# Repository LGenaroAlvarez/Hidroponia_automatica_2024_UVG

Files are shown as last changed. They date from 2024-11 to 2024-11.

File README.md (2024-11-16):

<picture>
 <source media="(prefers-color-scheme: dark)" srcset="https://github.com/LGenaroAlvarez/Hidroponia_automatica_2024_UVG/blob/f2462ae6608f58484dead54a124a67f43fbc2c54/Logo%20UVG-08.png" width="150" height="33">
 <source media="(prefers-color-scheme: light)" srcset="https://github.com/LGenaroAlvarez/Hidroponia_automatica_2024_UVG/blob/f2462ae6608f58484dead54a124a67f43fbc2c54/Logo%20UVG-06.png" width="150" height="33">
 LOGO-UVG
</picture>

# Diseño e implementación de un sistema hidropónico automático de técnica NFT para el cultivo de cilantro en un entorno urbano

## Autor
**Nombre:** Luis Genaro Álvarez Sulecio

**Carné:** 20168

**Carrera:** Licenciatura en Ingeniería Mecatrónica

### Información de contacto
**Correo institucional:** alv21068@uvg.edu.gt

**Correo personal:** luis.genaro.alvarez@gmail.com

**LinkedIn:** [L. Genaro A. Sulecio](https://www.linkedin.com/in/l-genaro-a-sulecio-4034471aa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)

## Asesor
**Nombre:** Ing. Pedro Joaquín Castillo Coronado
### Información de contacto
**Correo institucional:** pjcastillo@uvg.edu.gt

## Contenido
| Ubicación | Descripción de archivos|
|---|---|
| Codigo Fuente | Código desarrollado para el moniotoreo y control del sistema (firmware) y código de la aplicación desarrollada en Android Studio |
| Datos | Recopilación de históricos de datos obtenidos durante los períodos de prueba del sistema hidropónico tanto en formato .csv como en formato .xlsx |
| Documentos | Protocolo y trabajo escrito del proyecto de graduación desarrollado en TeXstudio |
| Modelos CAD | Modelos 3D de las piezas diseñadas e utilizadas en el sistema, ensamblaje del sistema completo para visualizaión 3D y planos detallados para cada pieza diseñada |
| Desarrollo PCB | Diagramas de circuitos, archivos de ruteo e imágenes de la placa desarrollada | 
| OldVersions | Versiones previas de código desarrollado |

## Descripción
 Este repositorio cuenta con la documentación del sistema hidropónico automático utilizando técnica de solución nutritiva recirculante (NFT por sus siglas en inglés) desarrollado como trabajo de graduación. El proyecto establece las bases para crear un sistema funcional que permita el monitoreo de diferentes parámetros ambientales que influyen en el crecimiento de las plantas en un entorno hidroónico. El sistema utiliza la placa de desarrollo [ESP-WROOM-32 de HiLetgo](http://www.hiletgo.com/ProductDetail/1906566.html) para recolectar datos de temperatura y humedad ambiental, así como de temperatura y pH de la solución de crecimiento. Para esto se utilizaron una serie de sensores analógicos y digitales los cuales se integraron utilizando diferentes librerías de licencia abierta.

 Este proyecto es el primero en la línea de investigación de **Agricultura de Precisión**.

## Desglose del sistema

### Firmware y software

* Sistema físico con lectura de sensores y control de actuadores, programado en la IDE de Arduino.
* Aplicación móvil para la visualización de la información recopilada por el sistema, programado en JAVA y XML.
* Sistema de registro de datos para generación de históricos, programado en Python.

### Controlador y sensores

* Sensores de temperatura y humedad ambiental [DHT11](https://www.adafruit.com/product/386)
* Sensores de temperatura del agua [DS18B20](https://www.adafruit.com/product/381)
* Sensor de pH en el agua [ENV-30-pH](https://atlas-scientific.com/kits/surveyor-analog-ph-kit/)
* Reloj de tiempo real RTC [DS3231](https://laelectronica.com.gt/modulo-de-reloj-rtc-ds3231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)
* Relés de 5VDC para control de elementos de 120VAC [Shori S3H-5-1CS](https://tienda.tettsa.gt/producto/relay-5vdc-5-pines-spdt-shori/)
* Placa de desarrollo [ESP WROOM-32](https://laelectronica.com.gt/modulo-wi-fi--bluetooth-esp32?search=esp32&description=true)

### Diseño de estructura física

La estructura física se basó al rededor de una estantería metálica modular. Esta cuenta con 5 repisas, de las cuales se utilizaron dos para los canales de crecimiento. En el ensamblaje del modelo CAD se observa la disposición de las tuberías para los canales de crecimiento, así como la posición de los sensores de temperatura y humedad ambiental.

<picture>
 ESTRUCTURA-SISTEMA-HIDROPONICO
</picture>

### Lenguajes de programación

* Python 3.11.9
* Arduino C
* Java
* XML

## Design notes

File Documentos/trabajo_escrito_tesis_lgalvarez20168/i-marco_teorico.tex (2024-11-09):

\section{Cultivos hidropónicos}
Históricamente, la agricultura tradicional ha utilizado el suelo como medio principal para el crecimiento de plantas gracias a su alta concentración de minerales y nutrientes esenciales para el desarrollo de hojas y frutos. Debido al crecimiento poblacional observado en los últimos siglos, las metodologías de agricultura tradicional han extraído una cantidad considerable de nutrientes del suelo, reduciendo su productividad y aumentando su dependencia de fertilizantes añadidos. 

A mediados del siglo pasado, se empezaron a investigar una técnicas de agricultura con tal de eliminar la dependencia del suelo para el crecimiento de las plantas. Una de las soluciones encontradas fueron los cultivos hidropónicos los cuales no dependen de un sustrato para entregar minerales y nutrientes esenciales para el crecimiento de las plantas, sino se aprovechan de una solución de estos en agua para maximizar la absorción por medio de las raíces \cite{raviv_soilless_2019}. Los sistemas hidropónicos se caracterizan por su bajo consumo de agua, alta eficiencia de espacio y altos niveles de productividad. Se destaca que estos sistemas no dependen de las condiciones climáticas de la región, al encontrarse en un entorno controlado, como un invernadero. Esto permite una producción constante a lo largo del año la cual no es susceptible a sequías o inundaciones. Adicionalmente, al no depender del suelo, estos sistemas se pueden expandir de manera vertical, lo cual aumenta la producción de plantas por metro cuadrado utilizado. Estas características han vuelto a la hidroponía una de las soluciones más prometedoras en el contexto del crecimiento urbano y poblacional visto en el siglo XXI. Otra de las grandes ventajas de contar con un entorno cerrado y controlable, es que los cultivos hidropónicos raras veces se encuentran expuestos a pestes o enfermedades relacionadas al suelo. Sin embargo, su dependencia de un control constante y riguroso de parámetros, hace de esta metodología de cultivo susceptible a pérdidas por mal manejo del sistema \cite{raviv_soilless_2019}.

\section{Solución nutritiva re-circulante (NFT)}
La hidroponía cuenta con una gran variedad de métodos ideados con la finalidad de maximizar espacio, eficiencia de distribución de materiales y otros parámetros de crecimiento de las plantas \cite{rajaseger_hydroponics_2023}. La principal diferencia entre los métodos de cultivo hidropónico consiste en los métodos de irrigación. El método de solución nutritiva re-circulante (\textit{Nutrient Film Technique}), también conocido como método NFT, utiliza un sistema de irrigación que genera una película delgada de agua con nutrientes que fluye sobre las raíces de las plantas. Tradicionalmente, estos sistemas se implementan con una serie de canaletas o tuberías colocadas a una inclinación de entre 0.3\% y 2\% \cite{van_os_technical_2019}. Una de las características más retadoras del método NFT consiste en el control de parámetros, como lo son los niveles de pH de la solución, su temperatura, oxígeno disuelto y saturación de nutrientes \cite{baiyin_flow_rate_2021}. Adicionalmente, varios estudios han demostrado que la tasa de flujo de la solución en el sistema se encuentra fuertemente relacionada con el rendimiento del crecimiento de las plantas. En el caso de las lechugas, Al-Tawaha y colaboradores encontraron que un flujo de 20 L/minuto fue óptimo para el desarrollo de las plantas, llevando a un mayor rendimiento \cite{al-tawaha_flow_rate_nft_2018}. Finalmente, es importante destacar que este sistema requiere que las plantas sean germinadas en un espacio separado, antes de que puedan ser introducidas al sistema.

\begin{figure}[H]
	\centering
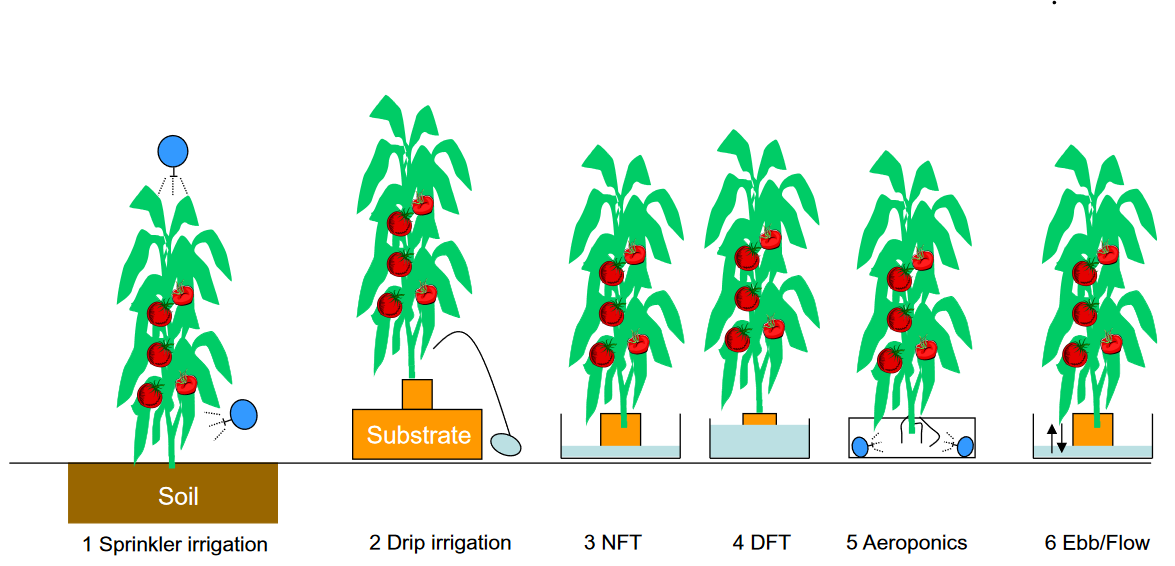
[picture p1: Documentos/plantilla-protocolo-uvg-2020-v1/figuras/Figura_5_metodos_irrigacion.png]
	
	\caption{Variedad de métodos de irrigación para cultivos \cite{van_os_technical_2019}.}
	\label{fig:mesh5}
\end{figure}

\begin{figure}[H]
	\centering
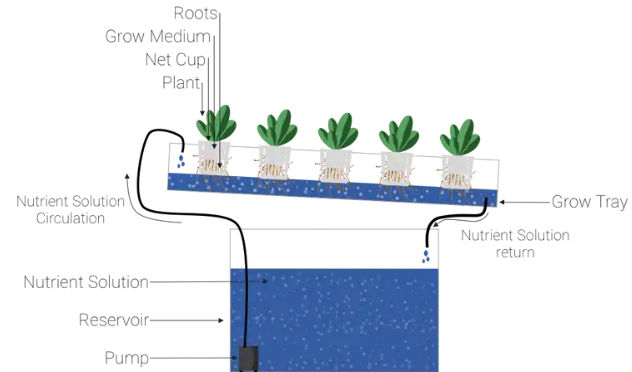
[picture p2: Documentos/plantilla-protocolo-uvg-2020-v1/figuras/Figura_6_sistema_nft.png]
	
	\caption{Diagrama simplificado de metodología NFT para cultivos hidropónicos \cite{NutrientFilmTechnique_2023}.}
	\label{fig:mesh6}
\end{figure}

\section{Solución de nutrientes}
Acceso constante a luz solar, agua, oxígeno y dióxido de carbono es esencial para la supervivencia de las plantas. Sin embargo, esto no es lo único que requieren para su crecimiento. Normalmente, las plantas obtienen la mayoría de los minerales y nutrientes necesarios para su crecimiento del suelo, el cual, a lo largo de varios años por procesos naturales, ha acumulado en diferentes cantidades. Las plantas requieren de 13 nutrientes minerales necesarios para su desarrollo y crecimiento adecuado. Sus características de crecimiento y la calidad de las plantas estarán definidas por el porcentaje de nutrientes que tengan disponibles y que sean capaces de absorber \cite{marulanda_huerta_2003}. Estos nutrientes se pueden dividir en tres categorías según la función que cumple cada elemento. La primera categoría se conoce como los macro-nutrientes, estos son nutrientes que las plantas requieren en altas cantidades pues son esenciales para el desarrollo de las estructuras fundamentales para su crecimiento. En este grupo se encuentran el Nitrato requerido para el desarrollo de hojas y tallos; el Fósforo, requerido para el desarrollo de raíces, la formación de semillas y la maduración de frutos; y el Potasio, requerido para el desarrollo de frutos y la acumulación de nutrientes en la planta \cite{marulanda_huerta_2003}.

La segunda categoría consiste en minerales requeridos para el correcto desarrollo de la planta, sin embargo, estos son requeridos en cantidades más bajas por lo que se conocen como elementos secundarios. Entre estos se encuentra el Calcio, el cual activa la formación de raíces, especialmente en las primeras etapas de desarrollo y neutraliza las sustancias tóxicas producidas por la planta. También se encuentra el Azufre, el cual es esencial en la producción de proteínas, mejora el crecimiento de la planta y facilita el desarrollo de semillas. Adicionalmente, en este grupo se cuenta con el Magnesio, el cual es fundamental para las plantas porque es requerido para la creación de clorofila y las azúcares que requieren para vivir, adicionalmente es utilizado para regular los nutrientes dentro de la planta y fomenta la creación de aceites y grasas \cite{marulanda_huerta_2003}. Finalmente, se cuenta con una serie de micro-nutrientes, los cuales cumplen una gran variedad de funciones que facilitan el desarrollo de la planta y aseguran un mayor rendimiento de la misma. Estos se detallan a continuación \cite{atlas_scientific_nutrient_2023}:

\begin{itemize}
	\item Cloro\\
	Utilizado para facilitar el proceso de fotosíntesis y regular los niveles de sales y líquido en las células lo cual asegura una planta fresca y saludable.
	\item Molibdeno\\
	Elemento esencial para la fijación de nitrógeno y utilizado en el proceso de conversión de nitrato a amoniaco.
	\item Manganeso\\
	De gran utilidad para aumentar la resiliencia de las plantas ante situaciones de alto estrés, y utilizado en el proceso de activación de enzimas.
	\item Zinc\\
	Requerido para la síntesis de hormonas de crecimiento y el desarrollo de raíces.
	\item Boro\\
	Apoya en el proceso de crecimiento al fomentar la división de células y el metabolismo de carbohidrátos.
	\item Hierro\\
	Esencial para la transferencia de energía entre células y la producción de clorofila.
	\item Cobre\\
	Mejora la estructura de las plantas al reforzar las paredes celulares mediante la formación de lignina. Esencial en la creación de estructuras maderosas.
\end{itemize}

El correcto suministro y balance de estos componentes en un sistema hidropónico es esencial para asegurar el crecimiento adecuado y el rendimiento de los cultivos. Ahora bien, su aplicación y control de manera individual sería sumamente difícil, por esta razón, se han desarrollado fórmulas para proveer estos nutrientes en un sistema hidropónico. En la industria estas soluciones se conocen como solución concentrada A y B, donde la primera cuenta con los macro-nutrientes y nutrientes secundarios, mientras que la segunda cuenta con los micro-nutrientes \cite{marulanda_huerta_2003}. Estas soluciones pueden ser creadas de manera independiente, o se pueden adquirir en el mercado. Es importante destacar que los porcentajes de concentración a utilizar en el sistema hidropónico dependerá del tipo de cultivo y sus requisitos. Por ejemplo, un cultivo de hortalizas requerirá mayores porcentajes de nitrógeno y nutrientes secundarios, mientras que plantas con flores y frutos, requerirán una mayor concentración de fósforo y potasio. Así mismo, cambios en la temperatura requerirán de un ajuste en la concentración total en el agua, puesto que, a mayores temperaturas, las plantas aumentarán su consumo de agua, mas no su dependencia en minerales, mientras que a menores temperaturas, se ve lo opuesto \cite{marulanda_huerta_2003}.

\section{Características de la solución nutritiva del cilantro}
El cilantro es una hierba bastante versátil la cual requiere de una baja cantidad de nutrientes con tal de presentar una productividad significativa. De los nutrientes mencionados anteriormente, el cilantro requiere únicamente un control rigoroso de los macro-nutrientes principales así como una baja cantidad de Calcio y Magnesio \cite{letpot_nodate}. Este control de macro-nutrientes va de la mano con una regulación cuidadosa de la temperatura del agua. Esto pues, en diferentes rangos de temperatura varía la necesidad de nutrientes así como su facilidad de absorción \cite{voogt_nutrient_2019}.

Según el estudio realizado por Currey y colaboradores, uno de los factores que más interfiere en el crecimiento y desarrollo del cilantro es la cantidad de fotones que reciben las plantas durante el día. Esto se puede traducir a la cantidad de horas de luz que requieren para su crecimiento óptimo, el cual se encuentra en un rango de 12 a 16 horas de luz diarias \cite{letpot_nodate}. Una conclusión importante del estudio de Currey y colaboradores es que si bien la concentración de luz disponible para la planta aumenta su productividad, no es necesario realizar un ajuste de la densidad de nutrientes debido al aumento en concentración de luz \cite{currey_nutrient_2019}. A continuación se detallan los parámetros del agua requeridos para el correcto desarrollo del cilantro en un sistema hidropónico:

\begin{table}[H]
	\centering
	\begin{tabular}{|c|c|}
		\hline
		\multicolumn{2}{|c|}{\textbf{Características de la solución nutritiva}}\\ \hline
		Concentración de nutrientes: & 1.2 a 1.8 mS/cm \\ \hline
		Potencia de hidrógeno (pH): & 5.5 a 6.7 \\ \hline
		Temperatura del agua: & 15 a 20 °C \\ \hline
		Nutrientes requeridos: & Nitrógeno, fósforo, potasio, calcio y magnesio \\ \hline
		Concentración de nutrientes: & NPK 15:15:15\\ \hline
		Nutrientes adicionales: &  0.5\% Nitrato de calcio y 0.5\% Sulfato de magnesio\\ \hline
		Tiempo de crecimiento: & 50 a 55 días\\ \hline
		Espacio entre plantas: & 18 cm \\ \hline
	\end{tabular}
	\caption{Parámetros esenciales para el crecimiento de Cilantro en sistemas hidropónicos \cite{mondol_use_2023} \cite{letpot_nodate}.}
	\label{Cuadro0}
\end{table}

\section{Monitoreo de parámetros para el crecimiento de plantas}
Como se detalló anteriormente, los cultivos hidropónicos requieren de un control constante y preciso de una gran variedad de parámetros. El monitoreo adecuado de parámetros como el nivel de oxigenación del agua, la cantidad de nutrientes, el nivel de acidez de la solución, la temperatura del ambiente, temperatura del agua, y el nivel de humedad son esenciales para asegurar el crecimiento óptimo de las plantas. Tradicionalmente, estos parámetros se miden con una serie de pruebas químicas o sensores independientes. A continuación, se detallan los diferentes sensores que se pueden utilizar en un cultivo hidropónico para medir los parámetros del agua así como la importancia de cada uno de dichos parámetros.

\subsection{Oxígeno disuelto en agua}
Los sistemas hidropónicos se enfrentan a varios retos, entre estos, la cantidad de oxígeno disuelto en la solución de nutrientes. Este parámetro es esencial para el desarrollo saludable de las raíces, puesto que con bajos niveles de oxígeno, estas pueden experimentar una enfermedad conocida como hipoxia. Según el estudio realizado por Roosta, los niveles de oxígeno están directamente relacionados no sólo con el crecimiento de las raíces, sino también con los procesos fotosintéticos y de crecimiento de los cultivos hidropónicos. Este parámetro afecta la absorción de Nitrógeno ya sea que se encuentre en la forma de sales de nitratos o amoníacos\cite{roosta_responses_2024}. La concentración de oxígeno disuelto se mide en mg/L, lo cual se puede lograr con una gran variedad de sensores.

\subsection{\textit{SEN0237 Gravity Analog Dissolved Oxygen Sensor} de \textit{DFRobot}}
El sensor analógico de oxígeno disuelto consiste en una sonda galvánica equipada con un electrodo el cual junto con una solución de hidróxido de sodio, también conocido como sosa cáustica, es capaz de detectar la concentración de oxígeno disuelto en agua. Dicho sensor debe ser calibrado antes de que se pueda utilizar, sin embargo, dicho proceso es relativamente sencillo \cite{DFRobot_DOsensor}. 

Según el fabricante, el sensor se puede calibrar utilizando un método de punto singular o de doble punto. El primer proceso requiere de la preparación de una solución de oxígeno concentrado en agua, esto se puede lograr utilizando un batidor o con una bomba de aire inmersa en el agua destilada durante 10 minutos. Una vez terminen los 10 minutos, se espera a que dejen de salir burbujas, y se sumerge la sonda en la solución. Se mantienen mezclando la solución lentamente para evitar burbujas hasta que el nivel de voltaje se estabilice y se guardan los valores de temperatura y voltaje como punto de saturación. El proceso de doble punto es similar al descrito anteriormente, sin embargo, requiere de dos soluciones a dos temperaturas diferentes. Se recomienda que una se encuentre alrededor de 5°C y la otra entre los 35° y 38°C \cite{DFRobot_DOsensor}. 

A continuación, se detallan las características del sensor:

\begin{table}[H]
	\centering
	\begin{tabular}{|c|c|}
		\hline
		\multicolumn{2}{|c|}{\textbf{Sonda del sensor de oxígeno disuelto}}\\ \hline
		Rango de detección: & 0 a 20 mg/L \\ \hline
		Rango de temperatura: & 0 a 40 °C \\ \hline
		Tiempo de respuesta: & 90 segundos a 25 °C \\ \hline
		Rango de presión: & 0 a 50 PSI \\ \hline
		Vida útil del electrodo: & 1 año (bajo condiciones normales de uso) \\ \hline
		Tiempo de reemplazo de membrana: & Cada 4 a 5 meses en agua clara \\ \hline
		Tiempo de reemplazo de solución: & Una vez al mes \\ \hline
		Largo del cable: & 2 metros \\ \hline
		Tipo de conector de la sonda: & BNC \\ \hline
		\multicolumn{2}{|c|}{\textbf{Placa de conversión de señales del sensor}}\\ \hline 
		Voltaje de alimentación: & 3.3 a 5.5 VDC \\ \hline
		Voltaje de señal de salida: & 0 a 3.3 VDC \\ \hline
		Cable de conexión: & BNC \\ \hline
		Conector de señal: & Interfaz PH2.0 - 3 pin \\ \hline
		Dimensiones: & 42mm $\times$ 32mm (1.65in $\times$ 1.26in) \\ \hline
	\end{tabular}
	\caption{Características de funcionamiento del sensor SEN0237 de \textit{DFRobot}.}
	\label{Cuadro1}
\end{table}

\begin{figure}[H]
	\centering
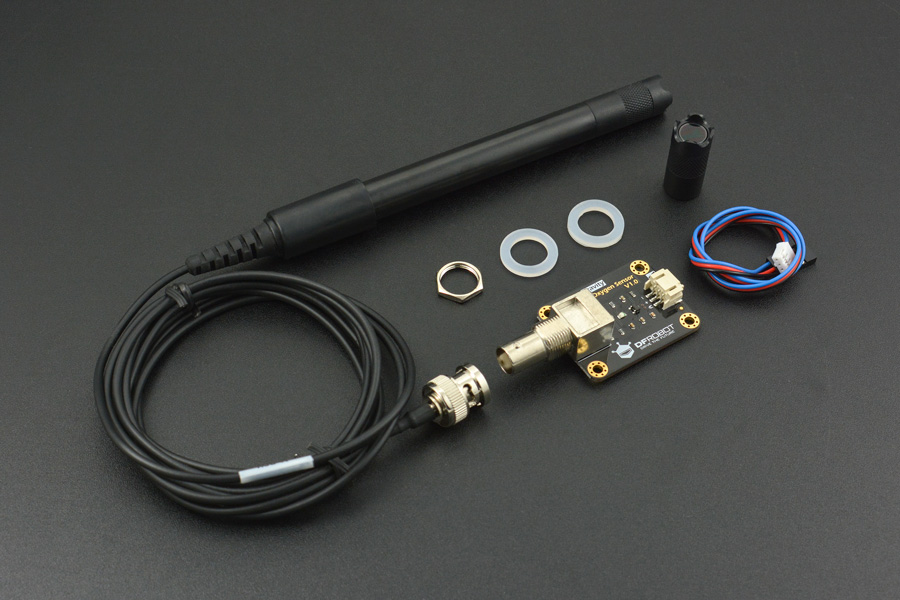
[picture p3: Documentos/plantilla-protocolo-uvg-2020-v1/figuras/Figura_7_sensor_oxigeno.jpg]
	
	\caption{Sensor analógico de oxígeno disuelto \cite{DFRobot_DOsensor}.}
	\label{fig:mesh7}
\end{figure}

\subsection{Sensor de electro conductividad (EC)}
Las soluciones de nutrientes requeridas para el crecimiento de las plantas cuentan con compuestos en la forma de sales, las cuales afectan la conductividad eléctrica del agua. Estas variaciones permiten utilizar los sensores de electro conductividad para determinar de manera aproximada la concentración de solución nutritiva en el agua de riego. La conductividad, medida en mS/cm (mili sievers por centímetro), es una propiedad de los materiales la cual se define como el inverso de la resistencia. El sensor \textit{DFR0300 Gravity Analog Electrical Conductividy Sensor} de \textit{DFRobot} cuenta con dos electrodos los cuales son introducidos en el agua para determinar su conductividad eléctrica, esta señal es luego convertida a un valor de voltaje analógico y transmitido a un microcontrolador \cite{DFRobot_ECsensor}. A continuación se detallan las características del sensor:

\begin{table}[H]
	\centering
	\begin{tabular}{|c|c|}
		\hline
		\multicolumn{2}{|c|}{\textbf{Sonda del sensor de conductividad eléctrica}}\\ \hline
		Constante de celda: & 1.0 \\ \hline
		Rango de detección admisible: & 0 a 20 mS/cm \\ \hline
		Rango de detección recomendado: & 1 a 15 mS/cm \\ \hline
		Rango de temperatura: & 0 a 40 °C \\ \hline
		Vida útil del sensor: & Más de 6 meses según frecuencia de uso \\ \hline
		Largo del cable: & 100 cm \\ \hline
		\multicolumn{2}{|c|}{\textbf{Placa de conversión de señales del sensor}}\\ \hline 
		Voltaje de alimentación: & 3.0 a 5.0 VDC \\ \hline
		Voltaje de señal de salida: & 0 a 3.4 VDC \\ \hline
		Certeza de medición: & $\pm 5\%$ F.S. \\ \hline
		Cable de conexión: & BNC \\ \hline
		Conector de señal: & Interfaz PH2.0 - 3 pin \\ \hline
		Dimensiones: & 42mm $\times$ 32mm (1.65in $\times$ 1.26in) \\ \hline
	\end{tabular}
	\caption{Características de funcionamiento del sensor DFR0300 de \textit{DFRobot}.}
	\label{Cuadro2}
\end{table}

\begin{figure}[H]
	\centering
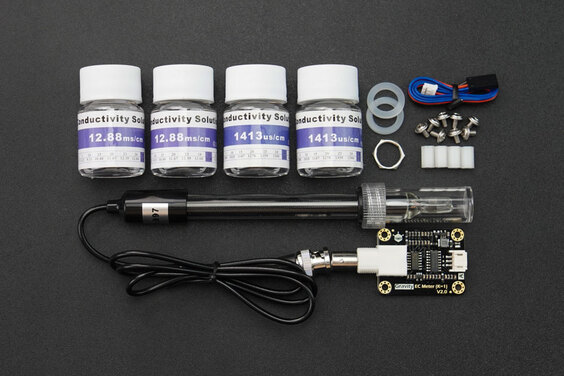
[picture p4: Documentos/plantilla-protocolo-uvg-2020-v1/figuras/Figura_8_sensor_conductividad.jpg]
	
	\caption{Sensor analógico de electro conductividad \cite{DFRobot_ECsensor}.}
	\label{fig:mesh8}
\end{figure}

\subsection{Potencia de hidrógeno (pH)}
El pH o potencia de hidrógeno se conoce como la facilidad con la que una sustancia en disolución libera protones de hidrógeno o iones de oxidrilo. Según esta definición, una sustancia ácida se caracteriza por una sustancia que libera protones de hidrógeno (H+) mientras que una sustancia básica es aquella que entrega iones de oxidrilo (OH-). La escala de pH es una función logarítmica que describe la relación entre estas propiedades de una solución. Esta se encuentra en un rango de 0 a 14, en donde 0 corresponde a una sustancia ácida, mientras que 14 indica una extremadamente básica \cite{chang_quimica_1995}. La solución de agua utilizada para alimentar las plantas en un cultivo hidropónico debe contar con un pH estable, usualmente definido por el tipo de planta que se desea cultivar. En el libro \textit{Plant Factory Using Artificial Light}, el autor Wada describe cómo la regulación de pH en las soluciones nutritivas no es sólo esencial para el crecimiento de las plantas, sino también para asegurar que los nutrientes se mantengan en su estado óptimo. Wada indica que un pH por encima de 7.0 induce la presipitación del Hierro y Manganeso, lo cual afectará la producción de clorofila y volverá a las plantas más susceptibles a estrés, mientras que un pH debajo de 4.5 implicará un daño a las raíces. La regulación de los niveles de pH en sistemas hidropónicos se pueden realizar mediante mediciones de electro conductividad, para determinar los porcentajes de bicarbonato en el agua, o utilizando un sensor de pH \cite{wada_theory_2019}. Ambos métodos presentarán resultados útiles para el control de dicho parámetro, sin embargo, contar con un sensor de pH permitirá obtener una lectura directa mientras que las lecturas de conductividad únicamente indicarán el pH según las sales presentes en la solución.

\subsection{Sensor de pH \textit{SEN0161 PH Meter} de \textit{DFRobot}}
Este sensor cuenta con una construcción sencilla la cual hace de este sensor fácil de utilizar. Al ser un sensor analógico, este requiere de un proceso de calibración utilizando soluciones cuyo pH sea conocido. Cuenta con un indicador led el cual se utiliza para determinar si el sensor se encuentra encendido o no. Adicionalmente, el conector utilizado para la placa de conversión de señales permite su fácil integración con placas de desarrollo como el Arduino o ESP32 \cite{DFRobot_PHsensor}. A continuación se detallan las características del sensor:

\begin{table}[H]
	\centering
	\begin{tabular}{|c|c|}
		\hline
		\multicolumn{2}{|c|}{\textbf{Sonda del sensor de pH}}\\ \hline
		Rango de detección: & 0 a 14 pH \\ \hline
		Rango de temperatura: & 0 a 60 °C \\ \hline
		Tiempo de respuesta: & Menor o igual a 1 minuto \\ \hline
		\multicolumn{2}{|c|}{\textbf{Placa de conversión de señales del sensor}}\\ \hline 
		Voltaje de alimentación: & 5.0 VDC \\ \hline
		Cable de conexión & BNC \\ \hline
		Conector de señal: & Interfaz PH2.0 - 3 pin \\ \hline
		Certeza de medición: & $\pm 0.1$pH a 25 °C. \\ \hline
		Dimensiones: & 42 mm $\times$ 32 mm (1.65 in $\times$ 1.26 in) \\ \hline
		Potenciómetro de ajuste de ganancia & Sí \\ \hline
		Indicador de potencia: & LED \\ \hline
		Largo del cable: & 660mm \\ \hline
	\end{tabular}
	\caption{Características de funcionamiento del sensorSEN0161 de \textit{DFRobot}.}
	\label{Cuadro3}
\end{table}

\begin{figure}[H]
	\centering
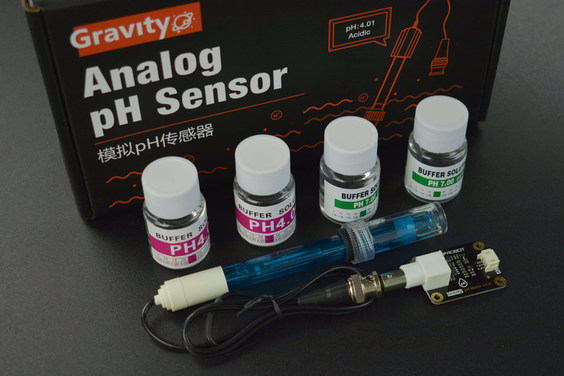
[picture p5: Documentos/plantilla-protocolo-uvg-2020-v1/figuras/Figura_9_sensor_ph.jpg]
	
	\caption{Sensor analógico de potencia de hidrógeno (pH) \cite{DFRobot_PHsensor}.}
	\label{fig:mesh9}
\end{figure}

\subsection{Temperatura de agua}
La temperatura del agua es de gran importancia para las plantas puesto que está directamente relacionado a la capacidad de absorción de nutrientes. Esta temperatura es de especial importancia en las raíces, puesto que variaciones en la temperatura de estas afecta tanto la micro-biología que se desarrolle en las raíces como la habilidad de las mismas para absorber nutrientes. Adicionalmente, la temperatura afectará la precisión de lecturas de electro conductividad así como pH y oxígeno disuelto \cite{voogt_nutrient_2019}. Es por esta razón que la lectura y el control adecuado de la temperatura del agua es esencial en un sistema hidropónico. 

\subsection{Sensor de temperatura de agua DS18B20}
Uno de los sensores más fáciles de utilizar es el sensor de temperatura tipo sonda DS18B20. Este sensor utiliza el protocolo de comunicación 1-wire, lo cual reduce considerablemente la complejidad de conexión y la transmisión de datos. A continuación se detallan sus características \cite{la_electronica_DS18B20}:

\begin{table}[H]
	\centering
	\begin{tabular}{|c|c|}
		\hline
		\multicolumn{2}{|c|}{\textbf{Sonda del sensor de pH}}\\ \hline
		Rango de medición: & -55 a 125 °C \\ \hline
		Voltaje de operación: & 3.5 a 5.0 VDC \\ \hline
		Protocolo de comunicación: & 1-wire \\ \hline
		Resolución programable: & 9 a 12 bits \\ \hline
		Largo de cable: & 1 metro \\ \hline
	\end{tabular}
	\caption{Características de funcionamiento del sensor DS18B20.}
	\label{Cuadro4}
\end{table}

\begin{figure}[H]
	\centering
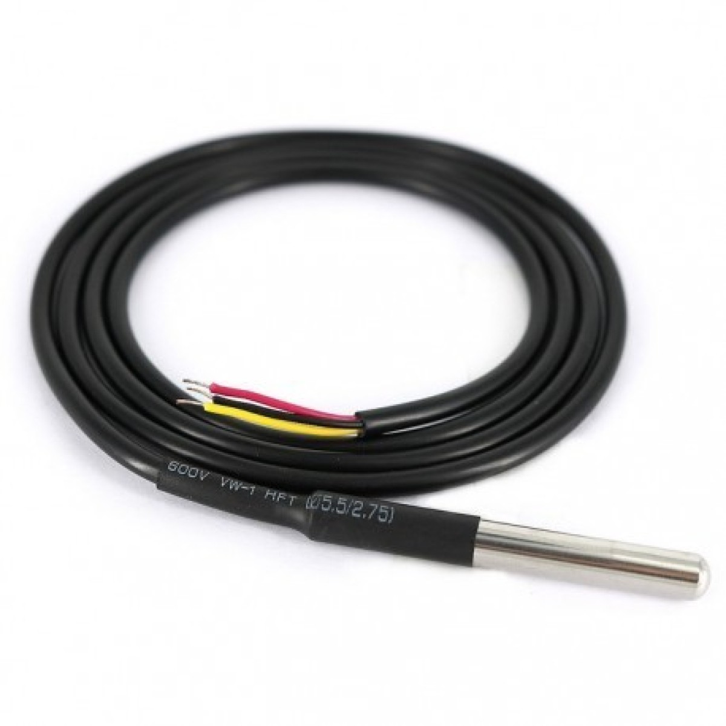
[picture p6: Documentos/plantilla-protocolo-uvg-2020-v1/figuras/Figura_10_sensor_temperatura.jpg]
	
	\caption{Sensor tipo sonda de temperatura del agua \cite{la_electronica_DS18B20}.}
	\label{fig:mesh10}
\end{figure}

\subsection{Temperatura y humedad ambiental}
Las plantas son organismos particularmente susceptibles a las condiciones ambientales, tanto a los niveles de luz como a la temperatura y humedad disponible. Estos parámetros afectan diferentes procesos de las plantas, desde la absorción de nutrientes hasta el desarrollo de las hojas. Según el estudio realizado por Chia y Lim, la humedad ambiental presentó un impacto significativo en el desarrollo de cultivos, donde se observó un aumento en la masa de las plantas luego de su cosecha \cite{chia_critical_2022}. Los autores describen como las plantas en un rango de humedad relativa (RH) alrededor del 85\% presentan un aumento en su masa seca. Destacaron que a mayores porcentajes de humedad, las plantas presentan dificultades con las razones de transpiración, regulación de agua, desarrollo de área superficial de las hojas y una disminución en absorción de nutrientes. Por otro lado, destacaron que a menores concentraciones de humedad, las plantas aumentan su consumo de agua junto con sus tazas de transpiración, lo cual puede presentar un riesgo en plantas que presentan dificultades en el control de las aperturas estomáticas, lo cual afecta los procesos de fotosíntesis \cite{chia_critical_2022}.

Al igual que la humedad ambiental, la temperatura del aire alrededor de las plantas afectará su crecimiento. En el estudio realizado por Rusu y colaboradores, se analizó el crecimiento de plantas de albahaca bajo condiciones controladas con tal de determinar el impacto de dichos parámetros en el desarrollo de las plantas. Se estableció que si bien el control de la temperatura de la solución es esencial para el correcto desarrollo delas plantas, la temperatura del ambiente es igual de importante. Esto se debe a que la temperatura ambiental afectará los procesos de transpiración de las plantas, el proceso de fotosíntesis, la conductividad estomática y el crecimiento de las estructuras de la planta \cite{rusu_overview_2021}. Por otro lado, ciertos compuestos bioactivos aumentan en concentración al estar en rangos de temperatura elevados (mayores a 30° C). Finalmente, los extremos de temperatura presentan un aumento en el estrés de las plantas, llevando a una mayor demanda de agua, lo cual puede aumentar la concentración de sales creando bloqueos \cite{bita_plant_2013}. 

\subsection{Sensor de temperatura y humedad DHT11}
El sensor DHT11 es uno de los sensores más básicos y de bajo costo disponibles en el mercado para la medición de temperatura y humedad relativa en el entorno. Cuenta con un sensor capacitivo el cual es capaz de detectar el porcentaje de humedad relativo en el aire, así como una termo-resistencia la cual es capaz de detectar cambios en la temperatura ambiental. \cite{adafruit_dht11} Este sensor utiliza el protocolo \textit{one-wire} lo cual minimiza los puertos a utilizar, y elimina la necesidad de puertos analógicos para realizar lecturas. Ahora bien, cuenta con un período de muestreo máximo de una lectura por segundo, lo cual hace que sea poco preciso en ambientes con alta variabilidad. A continuación se detallan las características del sensor.

\begin{table}[H]
	\centering
	\begin{tabular}{|c|c|}
		\hline
		\multicolumn{2}{|c|}{\textbf{Sensor DHT11}}\\ \hline
		Rango de medición de temperatura: & 0 a 50 °C \\ \hline
		Precisión de temperatura: & $\pm$ 2° C \\ \hline
		Rango de medición de humedad: & 20 a 80\% \\ \hline
		Precisión de humedad: & 5\% \\ \hline
		Voltaje de operación: & 3.0 a 5.0 VDC \\ \hline
		Corriente máxima: & 2.5mA \\ \hline
		Frecuencia de muestreo: & 1Hz \\ \hline
		Protocolo de comunicación: & \textit{1-wire} \\ \hline
	\end{tabular}
	\caption{Características de funcionamiento del sensor DHT11 \cite{adafruit_dht11}.}
	\label{Cuadro5}
\end{table}

\begin{figure}[H]
	\centering
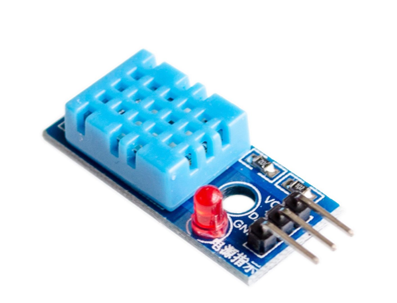
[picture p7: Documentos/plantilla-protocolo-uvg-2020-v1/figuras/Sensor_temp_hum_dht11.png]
	
	\caption{Sensor de temperatura y humedad DHT11 \cite{tettsa_dht11}.}
	\label{fig:mesh11}
\end{figure}
\newpage
\subsection*{Módulo RTC (reloj de tiempo real)}
Los módulos RTC cuentan con un reloj interno el cual puede ser utilizado para determinar la hora y fecha con gran precisión. El módulo DS3231 cuenta con un protocolo de comunicación el cual permite conectar varios sensores en serie, reduciendo la cantidad de entradas y salidas requeridas en placas de desarrollo. A continuación se detallan las características del módulo \cite{la_electronica_DS3231}:

\begin{table}[H]
	\centering
	\begin{tabular}{|c|c|}
		\hline
		\multicolumn{2}{|c|}{\textbf{Placa del módulo RTC DS3231}}\\ \hline
		Voltaje de alimentación: & 3.3 a 5.5 VDC \\ \hline
		Precisión de reloj: & Error de 1 minuto a temperatura entre 0 y 40 °C \\ \hline
		Salida programable de onda cuadrada: & Sí \\ \hline
		Chip de memoria: & AT24C32 con capacidad de almacenamiento de 32kB \\ \hline
		Dimensiones: & 38 mm $\times$ 22 mm $\times$ 14 mm \\ \hline
		Peso: & 8g \\ \hline
	\end{tabular}
	\caption{Características de funcionamiento del módulo RTC DS3231.}
	\label{Cuadro:caracter_rtc}
\end{table}

\begin{figure}[H]
	\centering
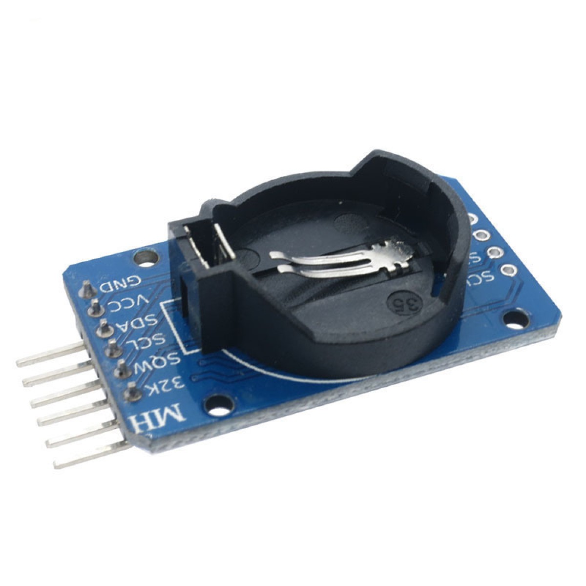
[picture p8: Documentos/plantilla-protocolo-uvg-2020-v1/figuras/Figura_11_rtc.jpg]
	
	\caption{Módulo RTC DS3231 \cite{la_electronica_DS3231}.}
	\label{fig:modulo_rtc}
\end{figure}

\section{Placa de desarrollo \textit{ESP-WROOM-32}}
La ejecución de los procesos de control así como la recolección de datos de los sensores instalados requiere del uso de un microcontrolador. Las placas de desarrollo de la familia ESP32 son de gran utilidad, puesto que permiten la fácil integración del módulo ESP32 en cualquier proyecto. El módulo ESP32 es uno de los microcontroladores más versátiles y de menor costo disponibles en el mercado. Este cuenta con conectividad WiFi, \textit{Bluetooth} v4.2, \textit{Bluetooth Low Energy}, pines analógicos, diferentes protocolos de comunicación serial y paralela, dos núcleos de procesamiento y compatibilidad con el lenguaje de programación de Arduino. Adicionalmente, las placas de desarrollo diseñadas alrededor de este microcontrolador cuentan con un costo reducido y bajo consumo eléctrico, lo cual lo hace ideal para aplicaciones con limitantes de costos. A continuación se detallan las características generales de la placa de desarrollo \textit{ESP-WROOM-32} \cite{electronic_wings_espwroom32}:

\begin{table}[H]
	\centering
	\begin{tabular}{|c|c|}
		\hline
		\multicolumn{2}{|c|}{\textbf{Placa de desarrollo \textit{ESP-WROOM-32}}}\\ \hline
		Procesador: & 2 núcleos hasta 240 MHz \\ \hline
		WiFi: & 2.4 GHz hasta 150 Mbits/s \\ \hline
		\textit{Bluetooth}: & \textit{Bluetooth Low Energy} y \textit{Bluetooth} v4.2 \\ \hline
		Arquitectura del procesador: & 32 bits \\ \hline
		Memoria RAM: & 520 KB \\ \hline
		Cantidad de pines IO: & 38 \\ \hline
		Cantidad de pines tipo ADC: & 16 \\ \hline
		Botones disponibles: & Botón de arranque y reinicio \\ \hline
		Leds disponibles: & Indicador LED de estado \\ \hline
		Puente USB a UART: & CP2102 \\ \hline
	\end{tabular}
	\caption{Características de funcionamiento y conexión de la placa de desarrollo \textit{ESP-WROOM-32}.}
	\label{Cuadro6}
\end{table}

\begin{table}[H]
	\centering
	\begin{tabular}{|c|c|}
		\hline
		\multicolumn{2}{|c|}{\textbf{Periféricos adicionales}}\\ \hline
		\multicolumn{2}{|c|}{Sensor capacitivo integrado}\\ \hline
		\multicolumn{2}{|c|}{Conversor Digital Analógico}\\ \hline
		\multicolumn{2}{|c|}{I2C (\textit{Inter-Internal Circuit})}\\ \hline
		\multicolumn{2}{|c|}{UART (\textit{Universal asyncrhonous receiver/transmitter})}\\ \hline
		\multicolumn{2}{|c|}{SPI (\textit{Serial Peripheral Interface})}\\ \hline
		\multicolumn{2}{|c|}{PWM (\textit{Pulse Width Modulated})}\\ \hline
	\end{tabular}
	\caption{Protocolos de comunicación y otros periféricos disponibles en el \textit{ESP-WROOM-32}.}
	\label{Cuadro7}
\end{table}

\begin{figure}[H]
	\centering
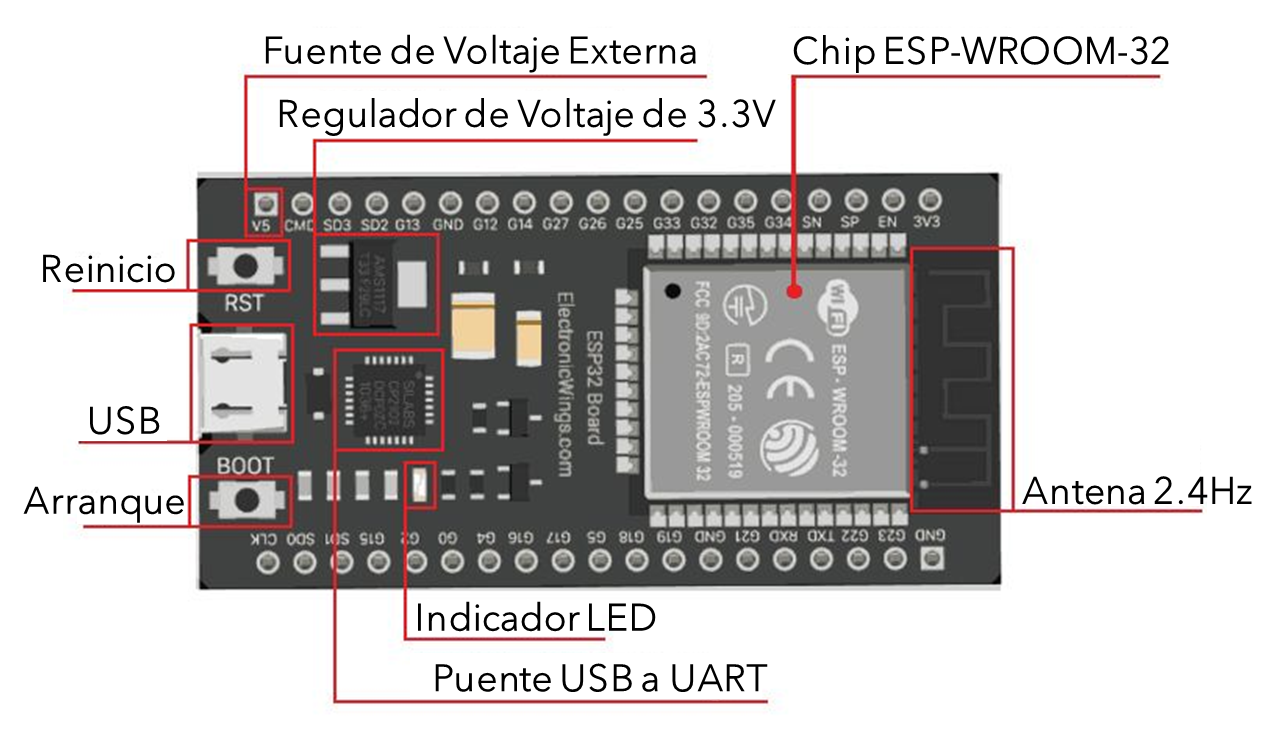
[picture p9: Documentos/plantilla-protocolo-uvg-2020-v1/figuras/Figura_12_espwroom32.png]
	
	\caption{Componentes de la placa de desarrollo ESP-WROOM-32 \cite{electronic_wings_espwroom32}.}
	\label{fig:mesh12}
\end{figure}

\section{Sistemas de control y conectividad con la nube}

\subsection{El internet de las cosas (IoT)}
El internet de las cosas se refiere a la capacidad de conectar objetos de uso cotidiano al internet para compartir parámetros de funcionamiento y otros datos entre diferentes dispositivos. La capacidad de compartir datos de manera inalámbrica con poca intervención humana hace de este proceso ideal para la automatización de procesos en diferentes sectores, desde el hogar hasta la ciudad entera. En general, los dispositivos IoT se pueden categorizar en sensores y actuadores o controladores, donde estos cumplen la función de recolectar datos y activar procesos respectivamente. Un sistema IoT básico funciona mediante un ciclo de retroalimentación constante de recolección, envío y análisis de datos para controlar diferentes eventos o indicar el estado de estos. El internet de las cosas se puede encontrar en una gran variedad de aplicaciones, desde la industria de manufactura, procesos de logística y transportación de productos hasta la agricultura. \cite{redhat_IoT_2019}

\begin{figure}[H]
	\centering
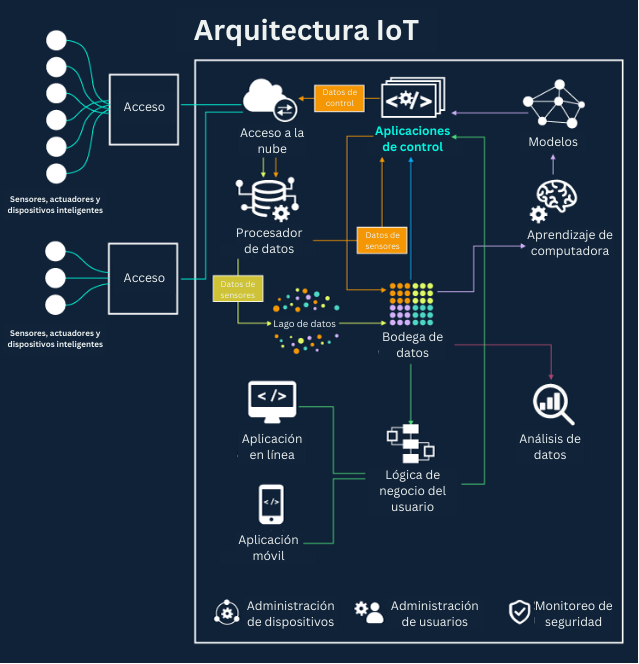
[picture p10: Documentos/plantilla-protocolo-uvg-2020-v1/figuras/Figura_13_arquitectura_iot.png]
	
	\caption{Diagrama de la arquitectura IoT generalizada \cite{grizhnevich_iot_2018}.}
	\label{fig:mesh13}
\end{figure}

\subsection{Protocolo de comunicación HTTP}
El internet funciona gracias a una serie de protocolos de comunicación que permiten la transferencia de datos como imágenes, texto, videos y audios entre servidores y usuarios. Uno de los protocolos fundamentales para la transmisión de estos datos es el protocolo HTTP (\textit{Hypertext Transfer Protocol}) o Protocolo de Transferencia de Hipertexto. La primera versión de HTTP para la transferencia de datos fue utilizada en 1990 como una herramienta para enviar datos a un usuario. Esta primera versión se conoce como HTTP/0.9. Esta iteración del protocolo se conoció como el protocolo de una línea, puesto que contaba con una gran cantidad de limitaciones, permitiendo únicamente realizar búsquedas de elementos como páginas escritas en HTML, imágenes o archivos específicos \cite{Evolution_http_Mozilla_2024}. Unos años después, gracias a un esfuerzo conjunto entre el MIT, \textit{Microsoft} y otras empresas, se desarrolló el protocolo HTTP/1.1. Una de las ventajas principales de este nuevo protocolo consistía en la adición de sistemas para el envío de datos a un servidor. Adicionalmente, se definieron nuevas reglas que permitieron que este sistema fuese más estable e incluso permitiera la transferencia de datos de manera simultánea \cite{fielding_hypertext_1999}. Este protocolo estableció los fundamentos para el desarrollo de futuras versiones, actualmente, las más utilizadas son  es la versión HTTP/2.0 y HTTP/3.0.

El protocolo HTTP consiste en el uso de una solicitud con una instrucción específica la cual es transmitida desde un usuario o cliente (\textit{client}). Esta solicitud se realiza mediante una conexión TCP o UDP dependiendo de la versión del protocolo, y cuenta con una estructura estandarizada para extraer, agregar, cambiar o eliminar información en el servidor. Una solicitud para retirar datos presenta la estructura observada en la Figura \ref{fig:mesh14}. Las palabras \textit{GET}, \textit{POST}, \textit{PUT}, \textit{PATCH} y \textit{DELETE} son utilizadas para indicarle al servidor durante la solicitud realizada las acciones a realizar. Adicionalmente, se especifica la dirección del servidor junto con información importante para la transacción y el contenido del mensaje en caso de que este sea requerido \cite{overview_http_mozilla_2024}.

\begin{figure}[H]
	\centering
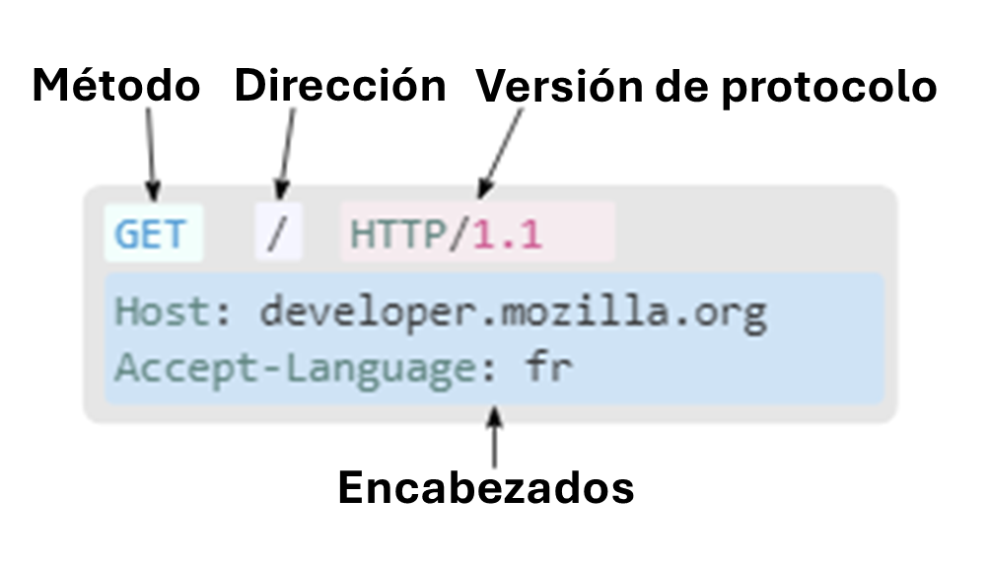
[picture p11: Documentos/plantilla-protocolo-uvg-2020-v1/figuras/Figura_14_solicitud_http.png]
	
	\caption{Estructura de una solicitud para retirar datos en el protocolo HTTP/1.1 \cite{overview_http_mozilla_2024}.}
	\label{fig:mesh14}
\end{figure}

Las solicitudes realizadas por el cliente son dirigidas directamente al servidor indicado en la dirección, sin embargo, usualmente se utilizan dispositivos intermedio para realizar dicha conexión. Una vez que el servidor recibe la solicitud, este devuelve una respuesta con un encabezado en el cual se detallan las características del archivo, así como ciertos códigos para indicar el estado de la conexión. Adicionalmente, la respuesta del servidor contará con la información solicitada por el cliente, ya sea esta un segmento de texto, un archivo, una página web o un video. Gracias a su simplicidad, este protocolo es el más utilizado hoy en día para intercambios de información en la red \cite{overview_http_mozilla_2024}.

\begin{figure}[H]
	\centering
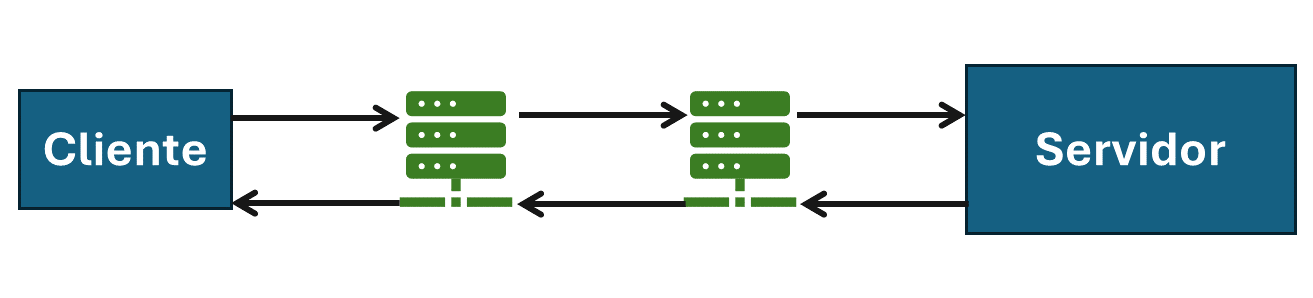
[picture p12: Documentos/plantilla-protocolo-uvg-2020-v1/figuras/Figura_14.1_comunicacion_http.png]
	
	\caption{Diagrama de la comunicación entre cliente y servidor mediante el protocolo HTTP \cite{overview_http_mozilla_2024}.}
	\label{fig:mesh14_1}
\end{figure}

\subsection{Comunicación WiFi con \textit{Dweet.io}}
\textit{Dweet.io} es un servicio abierto al público y totalmente gratuito que permite la transferencia de datos entre dispositivos funcionando como servidor para comunicaciones mediante HTTP. \textit{Dweet.io} utiliza un tema, llamado \textit{Thing}, el cual funciona como un servidor que recibe solicitudes mediante HTTP. Esta funcionalidad permite que diferentes dispositivos con conexión a la red puedan solicitar información almacenada o cargar nuevos datos a este servidor utilizando la dirección del tema. Una de sus mayores ventajas es que almacena datos en la forma de texto, el cual es distribuido en el cuerpo de las solicitudes HTTP. Esto permite almacenar diferentes valores de manera legible para cualquier humano, facilitando así el proceso de recolección e intercambio de datos. Es importante destacar que al ser gratuito, este servicio es completamente público y los mensajes pueden ser leídos por cualquiera con acceso a este servicio \cite{dweet_dweetio_faq}. Adicionalmente, los mensajes enviados a los servidores de \textit{Dweet.io} son almacenados únicamente durante 24 horas, a menos de que se pague una suscripción a un servidor privado.

\begin{figure}[H]
	\centering
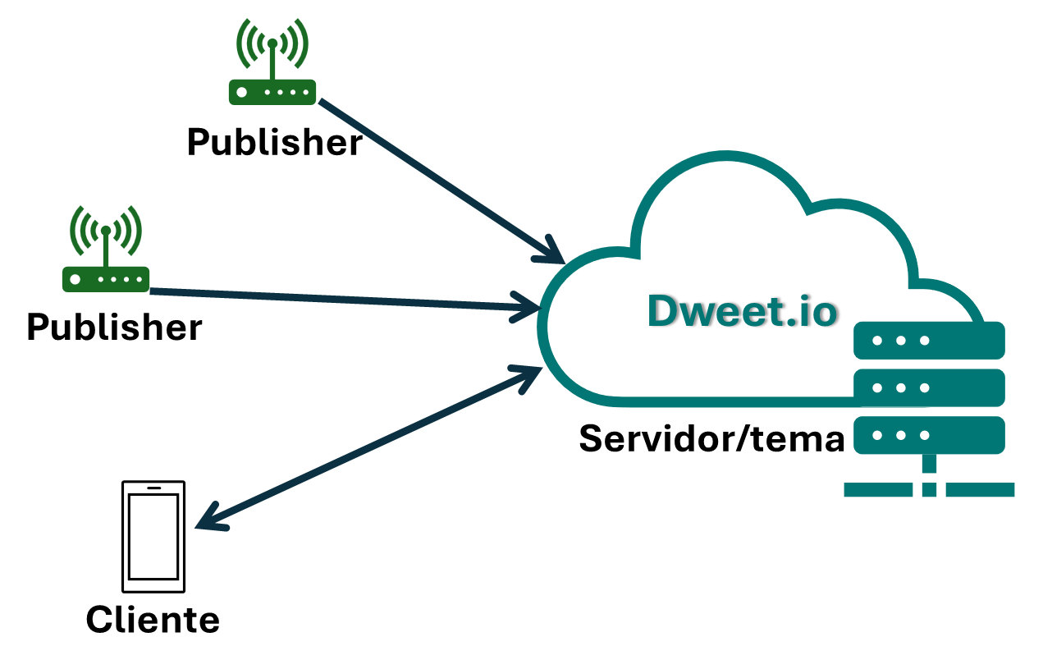
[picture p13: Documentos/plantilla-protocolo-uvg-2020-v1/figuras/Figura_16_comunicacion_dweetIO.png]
	
	\caption{Diagrama de la comunicación entre cliente y servidor de \textit{Dweet.io}.}
	\label{fig:mesh16}
\end{figure}

\subsection{Controladores de Fuzzy Logic}
En el área de control de sistemas, existen casos en donde el sistema a controlar presenta una gran cantidad de entradas y salidas así como una alta complejidad matemática en las variables de estado que lo definen, en la forma de no linealidades. En estos casos, el desarrollo de un modelo matemático que sea capaz de describir adecuadamente todas las relaciones entre variables llega a ser demasiado complejo, por lo cual se buscan alternativas para el control. Uno de los métodos diseñados para el control de estos sistemas se basa en la teoría de \textit{Fuzzy Sets} el cual busca establecer rangos de funcionamiento lineales para las variables de control del sistema así como relaciones lineales entre los diferentes parámetros que estas controlan. Estos se logra mediante procesos matemáticos para obtener rangos que permitan un control adecuado del sistema, sin la realización de un modelo matemático que describa todas las dinámicas del sistema \cite{verbruggen_fuzzy_1999}.

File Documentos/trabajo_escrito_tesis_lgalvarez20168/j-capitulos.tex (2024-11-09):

%----------------------------------------------------------------------------------------------------------

\chapter{Diseño y ensamblaje del sistema hidropónico}

En el presente capítulo se detallan los procesos, metodologías, retos y soluciones encontradas durante el desarrollo de la estructura física del sistema hidropónico. Este proceso de desarrollo se puede segmentar en tres etapas esenciales: diseño de estructura, diseño de circuitos y la construcción del sistema. A lo largo de estas etapas se encontraron retos y dificultades, así como oportunidades de mejora luego de las pruebas de funcionamiento realizadas.

\section{Diseño de la estructura}

El proceso de diseño atravesó diferentes etapas de iteración, en las cuales se encontraron áreas de mejora que facilitaran el proceso de manufactura y adquisición de la estructura. Durante las etapas iniciales, se propuso una iteración la cual se centraba en un proceso de manufactura extenso, utilizando como base perfiles angulares de aluminio 6061-T6. Si bien este diseño de la estructura cumplía con algunos de los requerimientos, se determinó que el proceso de manufactura sería un factor considerable, por lo que se diseñó una nueva iteración utilizando una estructura base prefabricada. A continuación se detallan las iteraciones diseñadas así como las consideraciones generales que llevaron a la elección de la última iteración para su construcción.

\subsection{Requerimientos físicos y restricciones de espacio}

La estructura física del sistema funcionaría como la plataforma que integraría todos los componentes necesarios para el funcionamiento del sistema hidropónico automático. Entre estos, se resaltan el depósito de almacenamiento de solución nutritiva, los canales de crecimiento, las tuberías de distribución de agua, los diferentes sensores, ventiladores, luces de crecimiento y actuadores, así como el sistema de control y la fuente de potencia. Esto, junto con las restricciones de espacio establecidas en los objetivos específicos del presente trabajo de graduación, establecieron requerimientos críticos relacionados a la estructura del sistema los cuales se detallan a continuación:

\begin{itemize}
	\item Altura máxima aproximada de 1750 mm para acomodar espacio entre repisas de aproximadamente 400 mm.
	\item Ancho de repisas de 700 mm para acomodar plantas con un espacio de 180 mm entre sí.
	\item Adaptabilidad para instalar sensores, actuadores y demás elementos necesarios para el funcionamiento del sistema, tanto antes como después del ensamblaje de la estructura principal.
	\item Rigidez estructural para soportar el peso del agua circulando por el sistema.
	\item Resistencia a la corrosión debido a exposición a altos niveles de humedad.
	\item Repisas de madera o plástico rígidas que permitan realizar modificaciones como agujeros o ranuras para ventilación y fijación de componentes.
	\item Facilidad de construcción con un proceso de manufactura sencillo sin el uso de herramientas altamente especializadas.
\end{itemize}

\subsection{Primera iteración, estructura de aluminio}

Como se mencionó al inicio de esta sección, la primera iteración de la estructura principal se diseñó utilizando perfiles estándar de dos pulgadas de aluminio 6061-T6. Se seleccionó este material considerando su facilidad de corte, baja densidad y alta disponibilidad en el país. Adicionalmente, se consideró que esta aleación es resistente a la corrosión y admite fácilmente la aplicación de recubrimientos tanto estéticos como funcionales \cite{matweb_al6061_T6}. 

Como se observa en la Figura \ref{fig:alumin}, la estructura se diseñó utilizando cuatro perfiles verticales, unidos por una serie de perfiles horizontales para las repisas a distancias preestablecidas. Una de las primeras limitaciones observadas durante las etapas de evaluación de este diseño fueron los altos requerimientos de maquinado para su manufactura. Según el diseño elaborado, esta iteración requería agujeros y cortes precisos, los cuales serían necesarios para instalar tornillos de fijación y tuberías de distribución.

\begin{figure}[H]
	\centering
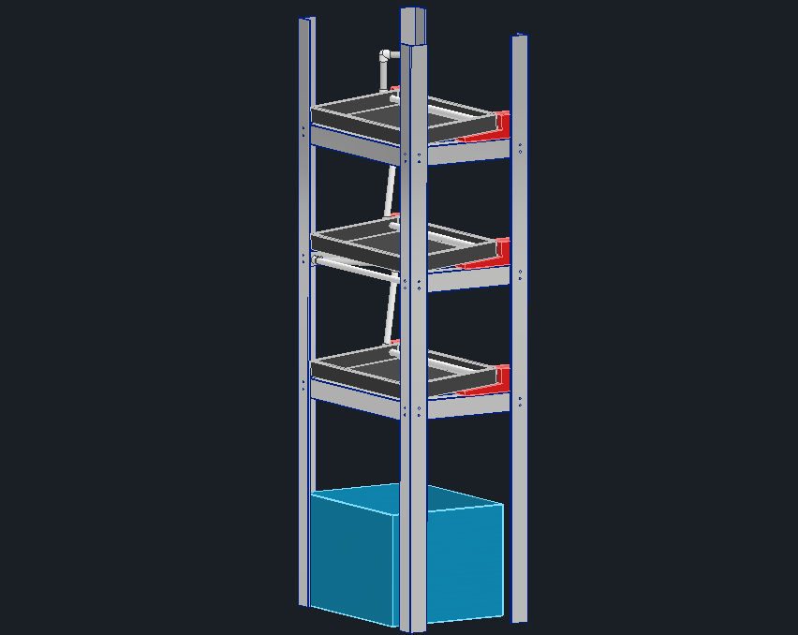
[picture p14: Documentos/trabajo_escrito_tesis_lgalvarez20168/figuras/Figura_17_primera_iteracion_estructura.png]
	
	\caption{Estructura inicial diseñada utilizando perfiles de aluminio de dos pulgadas.}
	\label{fig:alumin}
\end{figure}

Una vez completado el modelo CAD del sistema, se analizaron los requerimientos de manufactura. Si bien se eliminó la necesidad de realizar soldaduras en aluminio para unir los diferentes perfiles. Esta decisión de diseño implicó agregar una mayor cantidad de agujeros para elementos de fijación mecánicos. Por esta razón, el proceso de fabricación requeriría tanto del corte de los perfiles, utilizando cierra de calar u otras herramientas de corte afines, como el taladrado de agujeros. Adicionalmente, varios de los perfiles, como se observa en la Figura \ref{fig:perfil_h}, contaban con agujeros de diámetros mayores para tuberías, los cuales deberían ser maquinados en una máquina fresadora. Considerando los diferentes procesos de maquinado, se determinó que esta etapa de construcción requeriría de una inversión de tiempo considerable.

\begin{figure}[H]
	\centering
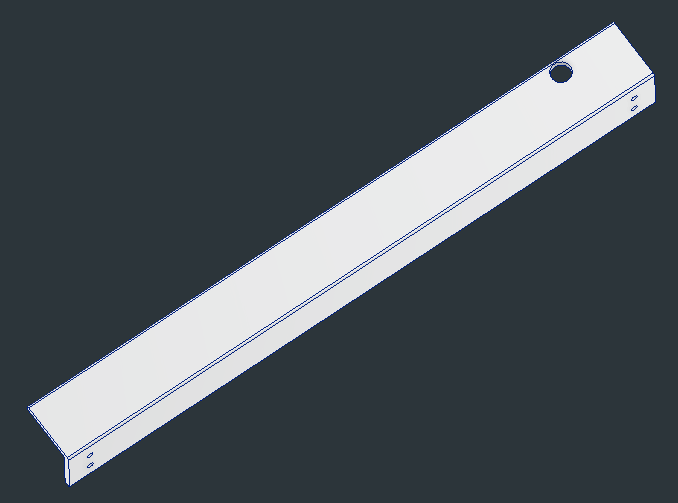
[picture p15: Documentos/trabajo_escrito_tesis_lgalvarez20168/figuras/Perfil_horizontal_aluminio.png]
	
	\caption{Perfil horizontal con perforación para tubería de distribución.}
	\label{fig:perfil_h}
\end{figure}
\newpage
\subsubsection{Canales de crecimiento}

Como se observa en la Figura \ref{fig:alumin}, en esta iteración se contempló el uso de bandejas de forraje las cuales permitirían el flujo del agua sobre su superficie, logrando así el suministro de nutrientes a las plantas. Adicionalmente, se utilizaron tuberías de PVC de 0.5 pulg, las cuales estarían a cargo de distribuir la solución nutritiva hacia las bandejas de crecimiento y entre cada nivel del sistema. Al utilizar tuberías de distribución para la solución nutritiva, se diseñaron perforaciones que serían necesarias en las bandejas de crecimiento para integrarlas con las tuberías. Adicionalmente, sería necesario implementar una cobertura para las bandejas de crecimiento, que mantuviera oscuro el entorno de las raíces, mientras que brindan una estructura de fijación para las plantas.

\begin{figure}[H]
	\centering
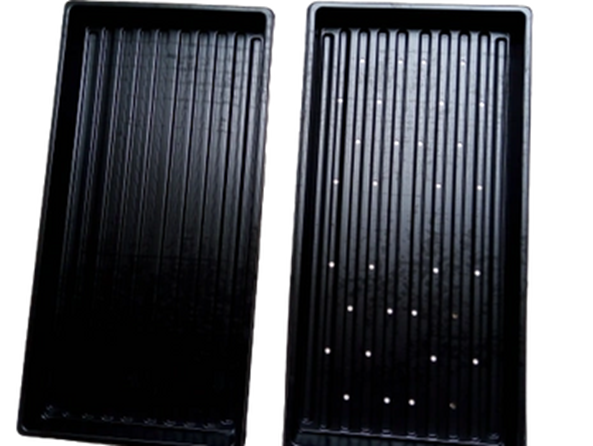
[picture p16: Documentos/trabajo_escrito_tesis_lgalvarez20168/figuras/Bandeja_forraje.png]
	
	\caption{Bandejas de forraje a utilizarse como canales de crecimiento.}
	\label{fig:bandeja_forraje}
\end{figure}

Una de las ventajas identificadas en las bandejas de forraje fue su versatilidad a la hora de distribuir las plantas. Sin embargo, se observó que las bandejas disponibles en el mercado guatemalteco, ver la Figura \ref{fig:bandeja_forraje}, contaban con canales que limitaban demasiado el flujo de agua, y podrían llevar a puntos secos. Estas áreas sin agua se deben a la irregularidad en el flujo del agua a través de la superficie de las bandejas, lo cual presentaría un riesgo significativo hacia las plantas. Adicionalmente, durante las etapas de diseño se determinó que la cantidad de material necesaria para cubrir las bandejas de crecimiento sería significativa. Estos cobertores para las bandejas requerirían de procesos de impresión por partes, lo cual dificultaría el proceso de construcción. Finalmente, las modificaciones necesarias para asegurar un flujo de agua constante entre las repisas generaría puntos de fuga los cuales podrían llegar a presentar un riesgo para el sistema. Por estas razones, se decidió iniciar una nueva iteración para el diseño del sistema.

\subsection{Segunda iteración, estructura prefabricada}

Si bien la primera iteración permitía una mayor flexibilidad en cuanto al diseño de la estructura, el proceso de fabricación dificultaba cualquier modificación que llegara a ser necesaria. Adicionalmente, al utilizar perfiles de aluminio, esta primera iteración requeriría de una gran cantidad de perfiles de aluminio, los cuales serían difíciles de transportar e instalar. Por esta razón, se inició una segunda iteración buscando utilizar una estructura prefabricada, la cual se pudiera adecuar de manera que fuera funcional en el sistema sin grandes modificaciones.

Luego de unas búsquedas en internet, se encontró una estantería de 1520 mm de altura y 760 mm de ancho. Adicionalmente, contaba con repisas de madera MDF con marcos de metal, las cuales podían ser instaladas a diferentes alturas. Como se observa en la Figura \ref{fig:estanteria_prefab}, se creó un modelo 3D de la estantería, con el cual fue posible observar los beneficios de esta selección en el diseño. Algunas de las ventajas incluyen a las estanterías de madera, las cuales se pueden modificar con facilidad y permiten el uso de tornillos de madera para la fijación de diferentes componentes. Así mismo, los perfiles con ranuras de ojo de cerradura, Figura \ref{fig:Perfil_slotted} se pueden aprovechar para instalar diferentes componentes en el sistema utilizando tornillos y tuercas sin la necesidad de modificar la estructura física. 

\begin{figure}[H]
	\centering
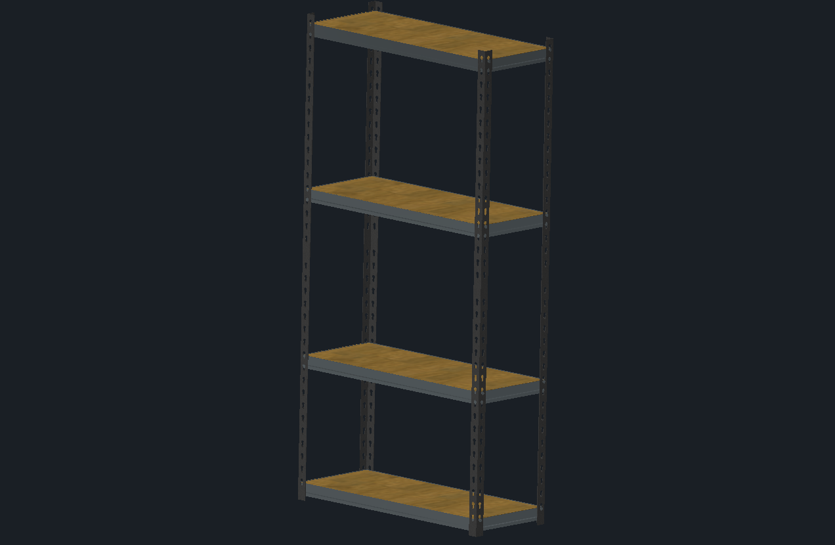
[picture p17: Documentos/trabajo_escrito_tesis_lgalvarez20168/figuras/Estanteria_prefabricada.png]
	
	\caption{Modelo 3D de la estantería prefabricada.}
	\label{fig:estanteria_prefab}
\end{figure}

\begin{figure}[H]
	\centering
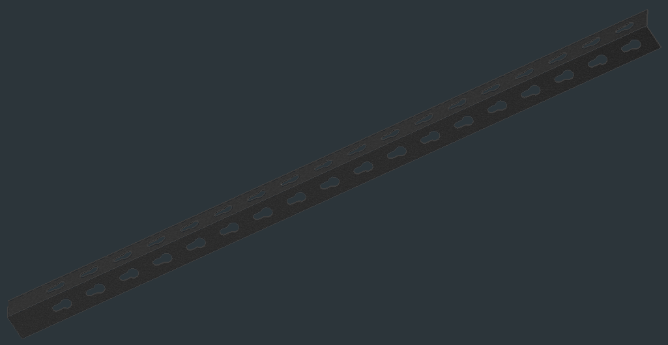
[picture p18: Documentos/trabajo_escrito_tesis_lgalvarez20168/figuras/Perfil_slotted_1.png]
	
	\caption{Perfil con ranuras de ojo de cerradura.}
	\label{fig:Perfil_slotted}
\end{figure}

\subsubsection{Canales de crecimiento}

Una vez se había definido la estructura de soporte del sistema en la segunda iteración, se continuó con el diseño del sistema de distribución de nutrientes. Con tal de mejorar la canalización del agua y asegurar que las raíces de las plantas recibieran una cantidad adecuada de agua, se seleccionaron tuberías de PVC para los canales de crecimiento de las plantas. Estas tuberías, además de asegurar que el agua se desplazara por una ruta predecible y predeterminada, facilitaban el proceso de construcción. Adicionalmente, estas tuberías de PVC se encontraban con facilidad en el mercado guatemalteco, y no requerían de grandes esfuerzos para su ensamblaje. Por otro lado, el uso de estas tuberías elimina la necesidad de encontrar una forma cubrir los canales de crecimiento, puesto que únicamente es necesario crear agujeros puntuales en la tubería para el crecimiento de las plantas. 

Al tomar en cuenta las consideraciones anteriores, se seleccionaron tuberías de 2.5 pulg, las cuales, junto con uniones de codo a 90° y uniones tipo T, permitirían la elaboración de los canales de crecimiento del sistema. Si bien la mayoría de las modificaciones necesarias para las tuberías consistirían en cortes, agregaron perforaciones de 2 pulg de diámetro las cuales permitirían introducir las canastas de crecimiento en las tuberías. Finalmente, se definió una orientación longitudinal para los canales de crecimiento, la cual permitiría instalar dos tiras de luces de crecimientocon una longitud aproximada de 500 mm en cada nivel. 

\begin{figure}[H]
	\centering
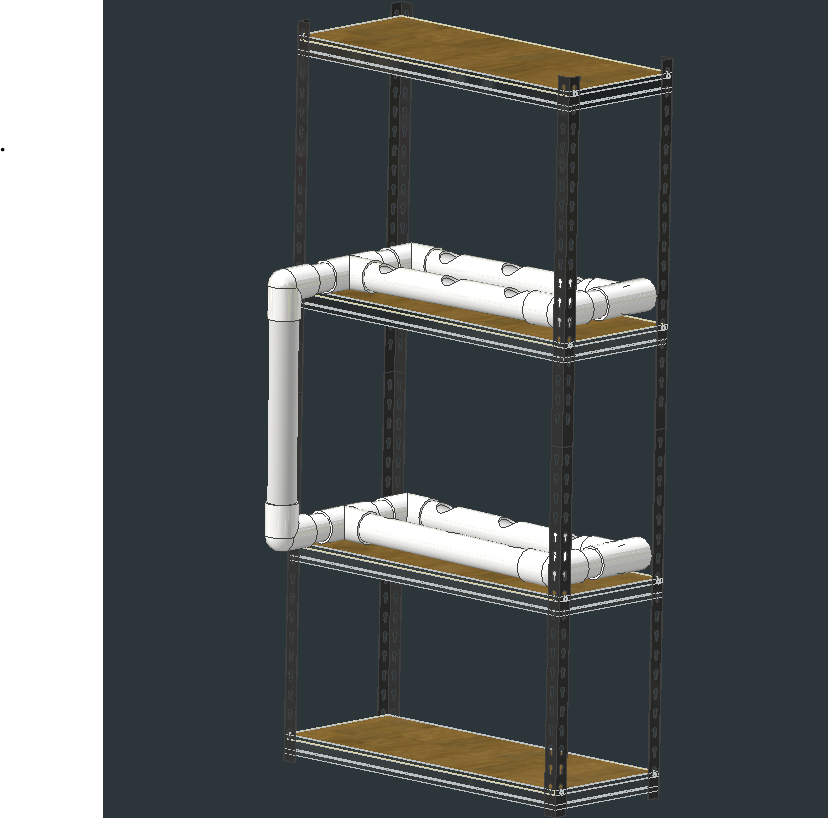
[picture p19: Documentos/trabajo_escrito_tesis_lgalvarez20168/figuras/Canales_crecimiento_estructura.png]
	
	\caption{Estructura con canales de crecimiento.}
	\label{fig:canales_crecimiento}
\end{figure}

Como se observa en la figura anterior, los canales de distribución de solución nutritiva y de crecimiento, se diseñaron completamente utilizando tuberías y accesorios de PVC. Esta decisión de diseño simplificó considerablemente su ensamblaje mientras que aseguraba un flujo adecuado para las plantas. Si bien las tuberías serían capaces de transportar el agua sin dificultad, aún sería necesaria una inclinación para asegurar el flujo constante de agua. Domando en cuenta la curvatura de las tuberías, se diseñaron dos soportes los cuales permitirían crear tanto una inclinación longitudinal como transversal. Estas inclinaciones serían necesarias para promover el flujo del agua desde el nivel superior hasta el inferior, y a través de las tuberías de crecimiento. Como se observa en la Figura \ref{fig:soporte_tub}, los soportes consistirían de piezas rectangulares con una sección semicircular inclinada a un ángulo de 0.8°, lo cual brindaría la pendiente necesaria para el flujo de agua requerido por el sistema. Estos soportes serían impresos en 3D para facilitar su manufactura, y se utilizarían tornillos para fijarlos a las superficies de las repisas. Cabe mencionar que se crearon dos soportes idénticos de alturas diferentes con tal de obtener una inclinación transversal entre las tuberías y asegurar así el flujo entre niveles.

\begin{figure}[H]
	\centering
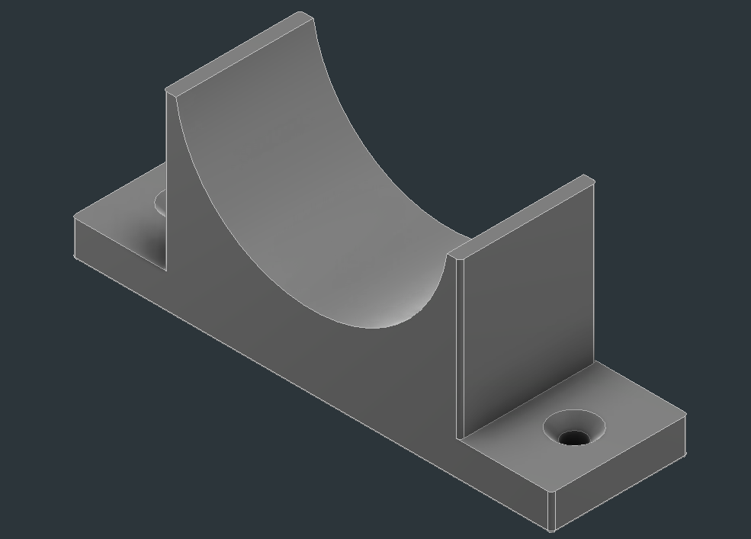
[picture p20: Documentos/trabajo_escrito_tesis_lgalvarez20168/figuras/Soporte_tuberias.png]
	
	\caption{Soporte con inclinación de 0.8° para tuberías de crecimiento.}
	\label{fig:soporte_tub}
\end{figure}

\subsection{Comparación de las iteraciones de diseño de la estructura}

Si bien la segunda iteración del diseño presentó grande mejoras en cuanto a la facilidad de ensamblaje y construcción, se realizó una comparación entre ambas iteraciones para determinar cuál sería utilizada en el sistema final. A continuación, se encuentra un cuadro comparativo en donde se evaluaron ambas iteraciones respecto a los requerimientos establecidos en la sección 7.1.1. del presente capítulo.

\begin{table}[H]
	\centering
	\begin{tabular}{|c|c|c|} \hline
		~ & \textbf{Primera iteración} & \textbf{Segunda iteración}\\ \hline
		\textbf{Altura max.} & 1750 mm & 1520 mm  \\ \hline
		\textbf{Ancho de repisas} & 586.7 mm & 760 mm \\ \hline
		\textbf{Adaptabilidad} & Pre construcción & Pre y post construcción \\ \hline
		\textbf{Rigidez estructural} & Media & Alta \\ \hline
		\textbf{Resistencia a la corrosión} & Alta & Media \\ \hline
		\textbf{Repisas de madera} & Sin repisas de madera & Repisas de MDF \\ \hline
		\textbf{Facilidad de construcción} & Manufactura compleja & Ensamblaje rápido \\ \hline
	\end{tabular}
	\caption{Análisis comparativo entre primera y segunda iteración de la estructura.}
	\label{cuadro:compar_iter}
\end{table}

Luego de analizar las características del diseño desarrollado para ambas iteraciones como se observa en el Cuadro \ref{cuadro:compar_iter}, se determinó que la segunda iteración sería la más factible para su desarrollo. Esto debido a que cumplió de mejor manera con los requisitos de facilidad de construcción, adaptabilidad \footnote{Esta se ponderó en función de la facilidad de realizar modificaciones una vez se haya instalado el sistema.} y rigidez estructural \footnote{Se determinó que la rigidez estructural de la primera iteración sería menor debido a una mayor altura y menor ancho de repisas, lo cual haría de la estructura menos estable}. Una vez se determinó estructura a utilizar, se iniciaron los procesos de diseño secundarios.

\subsection{Diseño de componentes auxiliares}

Luego del proceso de diseño de la estructura principal, se inició el diseño de los componentes que permitirían integrar la estructura principal con los sensores y actuadores requeridos. Con tal de facilitar el proceso de manufactura, se definieron las siguientes restricciones y consideraciones. Estas deberían ser cumplidas con todos los diseños realizados, asegurando un ensamblaje sencillo.

\begin{itemize}
	\item Simplicidad para impresión 3D: Para modelos pequeños, que su diseño cuente con chaflanes, redondeados y ángulos adecuados con tal de facilitar su manufactura utilizando impresoras 3D con materiales como PLA, ABS o PETG.
	\item Factibilidad de manufactura utilizando corte láser: En caso de que el modelo sea demasiado grande, que este pueda ser fabricado utilizando corte láser con materiales como MDF o acrílico.
	\item Facilidad de ensamble: Que los modelos se puedan ensamblar fácilmente utilizando tornillos u otros medios mecánicos.
\end{itemize}

Utilizando las consideraciones anteriores, se diseñaron dos componentes secundarios. En la Figura \ref{fig:soporte_dht} se observa el primer componente, utilizado para fijar los sensores de temperatura y humedad DHT11 a las repisas de crecimiento. Estos sujetadores para los sensores de DHT11 deberían permitir que se instalaran a una distancia cercana a la altura de las plantas. Esto para asegurar que los parámetros recolectados fueran representativos del entorno alrededor de las hojas y tallos en cada repisa. Para esto se definió el uso de una varilla de madera de 0.5 pulg de diámetro, la cual sería cortada a una longitud aproximada de 160 mm. Los sensores se acoplaron a un anillo, el cual sería fijado a las varillas mediante un tornillo para madera.

\begin{figure}[H]
	\centering
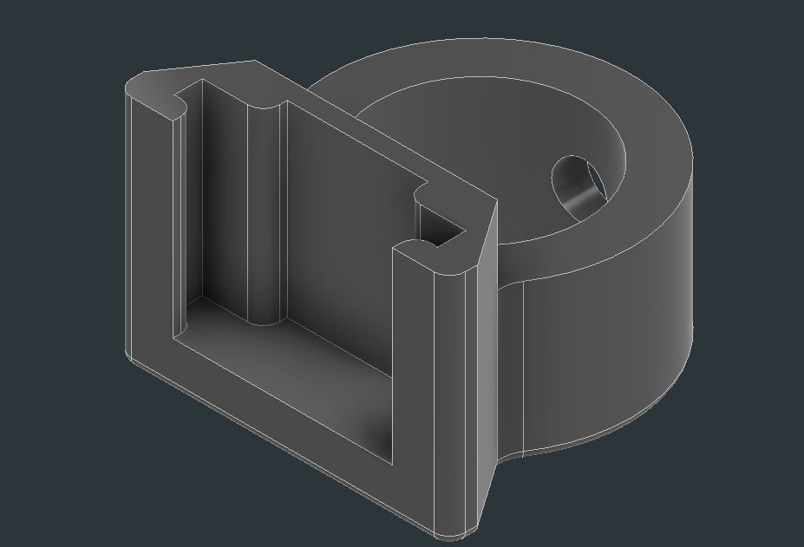
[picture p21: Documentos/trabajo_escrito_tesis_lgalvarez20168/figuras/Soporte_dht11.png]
	
	\caption{Soporte para sensores DHT11 en varillas de 0.5 pulg.}
	\label{fig:soporte_dht}
\end{figure}

En el caso del segundo componente, este se diseñó para fijar los ventiladores a la estructura de metal. Se diseñaron considerando los agujeros disponibles en cada ventilador para su instalación. Adicionalmente, se diseñó un agujero central que permitiría el uso de tornillos para fijar mecánicamente el soporte a los postes de metal, aprovechando las ranuras de ojo de cerradura. Como se observa en la Figura \ref{fig:soporte_vent}, este componente presenta una baja complejidad, facilitando el proceso de manufactura e instalación.

\begin{figure}[H]
	\centering
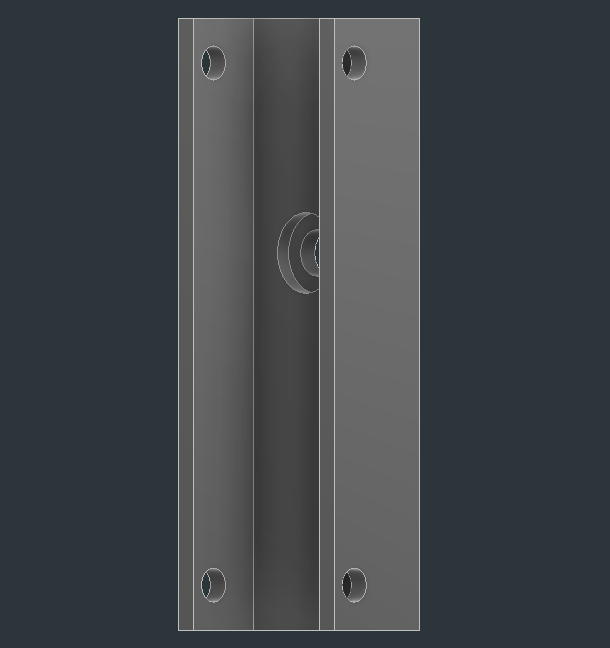
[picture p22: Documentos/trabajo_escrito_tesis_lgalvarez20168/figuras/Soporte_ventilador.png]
	
	\caption{Soporte para ventiladores con tornillos de 0.25 pulg.}
	\label{fig:soporte_vent}
\end{figure}

\subsection{Modelado CAD de la estructura}

Una vez finalizados los diferentes modelos a instalar en el diseño de la segunda iteración, se integraron todos los componentes para tener un modelo completo del sistema. Como se observa en la Figura \ref{fig:estanteria_v2}, este modelo cuenta con las tuberías de distribución, canales de crecimiento, tanque de almacenamiento de agua. Además, cuenta con las varillas para la sujeción de los sensores y demás componentes auxiliares.

\begin{figure}[H]
	\centering
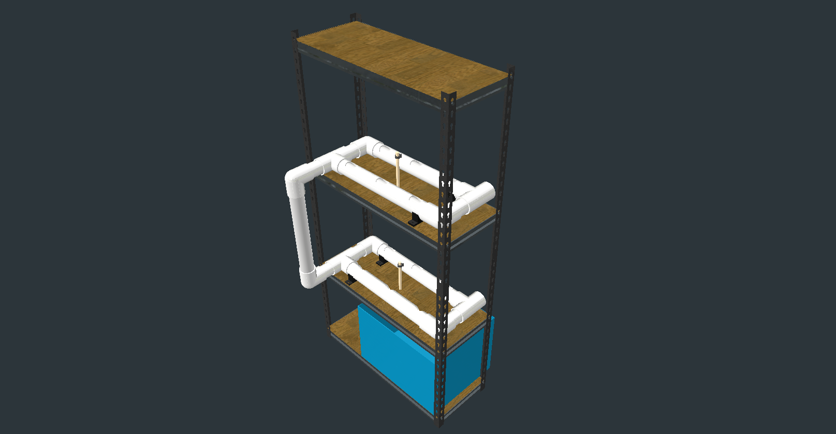
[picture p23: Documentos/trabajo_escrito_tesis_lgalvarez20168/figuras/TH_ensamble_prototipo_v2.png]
	
	\caption{Ensamblaje del modelo CAD de la estructura principal del sistema.}
	\label{fig:estanteria_v2}
\end{figure}

Con este modelo establecido, fue posible continuar con el proceso de construcción, el cual se discutirá en la sección 7.3. del presente capítulo.

\section{Diseño de circuitos}

El sistema de control se basó en el microcontrolador ESP-WROOM32 y la placa de desarrollo de \textit{Hiletgo} ESP-32S. Esta placa se utilizó para obtener información de los diferentes sensores y activar los actuadores conectados al sistema. Debido al uso de un microcontrolador con una placa de desarrollo, la mayor parte de los circuitos del sistema se categorizaron como conexiones de componentes digitales. Si bien esto redujo la complejidad del proceso en el diseño de los circuitos, se encontraron varios retos relacionados a niveles de voltaje y disponibilidad de conexiones en la placa de desarrollo. A continuación, se detallan las diferentes etapas consideradas en el diseño del sistema electrónico.

\subsection{Características de alimentación de potencia}

Desde el controlador hasta los sensores, luces y actuadores requieren de una alimentación regulada de voltaje CC (corriente continua). Como se discutió en el capítulo 6, la mayoría de los componentes utilizados cuentan con un rango de voltaje de operación entre los 3 y 5.5 voltios CC. Por otro lado, los ventiladores a utilizar en el sistema consistirían de ventiladores de corriente alterna, por lo que sería necesario acceso a una línea de 120 voltios CA (corriente alterna). Por estas razones, la fuente seleccionada debería ser capaz de entregar un voltaje de 5 voltios CC y ser capaz de funcionar con una entrada de 120 voltios CA. Adicionalmente, en el capítulo 6 se detallaron las características de consumo de corriente de los sensores a utilizar, con las cuales se calculó un consumo máximo de corriente de 5 amperios, según se observa en el Cuardo \ref{cuadro:corriente_sensores}.

\begin{table}[H]
	\centering
	\begin{tabular}{|c|c|c|} \hline
		\textbf{Componente} & \multicolumn{2}{c|}{\textbf{Corriente máxima}} \\ \hline
		2 sensores DHT11 & 10 & $mA$ \\ \hline
		3 sensores DS18B20 & 12 & $mA$ \\ \hline
		Sensor PH SEN0161 & 600 & $mA$ \\ \hline
		Sensor DFR0300 & 600 & $mA$ \\ \hline
		Sensor SEN0237 & 600 & $mA$ \\ \hline
		Relé Shori S3H-5-1C-S & 72 & $mA$ \\ \hline
		RTC DS3231 & 575 & $\mu A$ \\ \hline
		ESP-WROOM-32 & 1.5 & $A$ \\ \hline
		Total: & 3.4 & $A$ \\ \hline
	\end{tabular}
	\caption{Corriente máxima requerida por los componentes del circuito.}
	\label{cuadro:corriente_sensores}
\end{table}

Al considerar el consumo de corriente total de los componentes principales, así como las demás características mencionadas, se seleccionó una fuente de alimentación conmutada de 5 voltios a 5 amperios. Se optó por esta fuente puesto que se alimentaba utilizando 120 voltios CA, dejando terminales de conexión disponibles para conexiones de 120 VCA y los 5 VCC, requeridos. Adicionalmente, estas fuentes cuentan con una salida de voltaje estable, gracias a su control por variación de ancho de pulso, asegurando un voltaje constante.

\subsubsection{Pruebas físicas de circuitos principales}

Una vez seleccionada la fuente de alimentación, se realizaron una serie de pruebas con los diferentes componentes del sistema. Estas se dividieron en tres etapas, una para pruebas con sensores de temperatura, otra para ventiladores, y una última para luces de crecimiento. Luego de estas pruebas, se inició el proceso de integración de componentes, implementando los ajustes que se consideraron necesarios.

Durante la primera etapa de pruebas, se conectaron los sensores DHT11 junto con los sensores de temperatura de agua DS18B20. Adicionalmente, se conectó el microcontrolador, el cual contaba con la programación requerida para la lectura de los valores entregados por los sensores de temperatura. En esta etapa de pruebas, se determinó que la corriente y el voltaje eran suficientes para el funcionamiento adecuado de los sensores. Ahora bien, se detectaron ciertos fallos de conexión, los cuales llevaron a caídas de voltaje inesperados. Por otro lado, en la segunda etapa de pruebas, se conectaron los ventiladores utilizando relés transistorizados. Durante estas pruebas, se confirmó el funcionamiento de los relés y ventiladores, los cuales estarían combinando un circuito de 120 voltios CA y 5 voltios CC. Finalmente, en la tercera etapa se conectaron las tiras de leds, las cuales en combinación, llegaron a una longitud de 2 metros. De las pruebas realizadas, la prueba con las tiras de luces led presentó problemas respecto a la demanda de corriente de las tiras. Como se demuestra a continuación, el consumo de las tiras de luces led incrementó considerablemente, por lo que se volvió a evaluar el consumo del sistema \footnote{Luego de investigar la hoja de datos de las luces utilizadas, se encontró que estas contaban con un consumo máximo de 0.036 $mA$ por luz, por lo que una tira de 120 luces, contaría con un consumo total de 4.32 $A$.}.

\begin{table}[H]
	\centering
	\begin{tabular}{|c|c|c|} \hline
		\textbf{Componente} & \multicolumn{2}{c|}{\textbf{Corriente máxima}} \\ \hline
		2 sensores DHT11 & 10 & $mA$ \\ \hline
		3 sensores DS18B20 & 12 & $mA$ \\ \hline
		Sensor PH SEN0161 & 600 & $mA$ \\ \hline
		Sensor DFR0300 & 600 & $mA$ \\ \hline
		Sensor SEN0237 & 600 & $mA$ \\ \hline
		Relé Shori S3H-5-1C-S & 72 & $mA$ \\ \hline
		RTC DS3231 & 575 & $\mu A$ \\ \hline
		ESP-WROOM-32 & 1.5 & $A$ \\ \hline
		Neopixel WS2812B & 4.32 & $A$ \\ \hline
		2 servomotores MG90S & 1.6 & $A$ \\ \hline
		Total: & 9.31 & $A$ \\ \hline
	\end{tabular}
	\caption{Corriente máxima requerida por el sistema completo de voltaje CC.}
	\label{cuadro:corriente_maxima}
\end{table}

Al analizar nuevamente el consumo de corriente, se determinó que sería necesaria una fuente de alimentación conmutada capaz de entregar como mínimo 10A. Si bien durante el funcionamiento del sistema completo, no todos los componentes estarían consumiendo su corriente máxima al mismo tiempo, esta es una posibilidad que no se debe descartar. Con tal de mejorar el factor de seguridad, se consideró el uso de una fuente conmutada de 15 amperios, sin embargo, no se encontraban disponibles en el país al momento de realizar las pruebas.

Gracias a las pruebas realizadas, se observaron ciertos cambios en el comportamiento del microcontrolador en diferentes etapas de funcionamiento del circuito. Se observó que durante ciclos de conexión a una red WiFi, así como durante el uso de las luces de crecimiento, el microcontrolador tendía a perder potencia. Esto a pesar de que el módulo de conversión de voltaje disponible en la placa de desarrollo es considerablemente robusto ante variaciones de voltaje. Debido a esto, se consideró la implementación de un banco de capacitores. Dicha modificación al circuito logró estabilizar el voltaje de alimentación del ESP-32S y presentó mejoras considerables durante los ciclos mencionados.

\subsection{Configuración de conexiones para sensores y actuadores}

Durante la etapa de diseño del circuito, fue necesario incluir componentes analógicos necesarios para la regulación del voltaje y para mantener sus características de funcionamiento. Estos se resumen en resistencias y transistores, los cuales se utilizaron para regular la corriente en pines específicos. 

\subsubsection{Circuito de control de relés}

El microcontrolador ESP-32S, cuenta con salidas lógicas en sus pines digitales de 0 a 3.3 voltios CC, lo cual no sería capaz de controlar los relés de 5 voltios CC utilizados en el sistema. Por esta razón, se utilizó un transistor BJT, el cual sería capaz de controlar el flujo de corriente entre su colector y emisor utilizando el voltaje de la señal digital del microcontrolador. Al tomar en cuenta este requerimiento en el diseño, se calculó la corriente de saturación del transistor al ser alimentado con 3.3 voltios CC.

\begin{table}[H]
	\centering
	\begin{tabular}{|c|c|c|} \hline
		\multicolumn{3}{|c|}{\textbf{Características principales}} \\ \hline
		Ganancia DC ($\beta$) & 100 & ~ \\ \hline
		Corriente de saturación & $I_B$=15 & $mA$ \\ \hline
		Voltaje de saturación $V_{BE}$ & 1.2 & $V$ \\ \hline
		Corriente requerida $I_C$ & 72 & $mA$ \\ \hline
	\end{tabular}
	\caption{Características de los transistores NPN 2N222A y del circuito.}
	\label{cuadro:2n222a_caracter}
\end{table}

Con tal de calcular la resistencia de base necesaria para controlar los relés, se emplearon las siguientes ecuaciones:

\begin{equation}
	I_B = \frac{I_C}{\beta}
	\label{eq:I_B_colector}
\end{equation}

\begin{equation}
	I_B = \frac{V_B-V_{BE}}{R_B}
	\label{eq:I_B_resistor}
\end{equation}

De la ecuación \ref{eq:I_B_colector} se obtuvo una corriente de base $I_B = 72$ $\mu A$. Ahora bien, esta corriente no sería suficiente para saturar el transistor, como se observa en el Cuadro \ref{cuadro:2n222a_caracter}, la corriente de saturación debe ser de 15 $mA$. Utilizando esta corriente, se calculó el valor de la resistencia a utilizar, considerando que el voltaje de la base en su estado activo sería de $V_{B} = 3.3$ V. De la Ecuación \ref{eq:I_B_resistor} se despejó para la resistencia. Al ingresar los valores requeridos en la ecuación despejada se obtuvo $R_B = \frac{3.3V-1.2V}{0.015mA}$, resultando en un valor de $R_B = 140$ $\Omega$.

Con tal de utilizar un valor de resistencia comercialmente disponible, se propuso el uso de resistencias de 100 $\Omega$. Se realizó una comprobación aplicando la Ecuación \ref{eq:I_B_resistor}, con la cual se obtuvo una corriente base $I_B = 21$ $mA$. Al tomar en cuenta que para lograr la saturación, se debe cumplir la siguiente relación: $I_C < \beta I_B$, se determinó que la resistencia seleccionada sería adecuada para activar el relé a utilizar. Del análisis anterior, se derivó el diagrama de la Figura \ref{fig:diag_rele}.

\begin{figure}[H]
	\centering
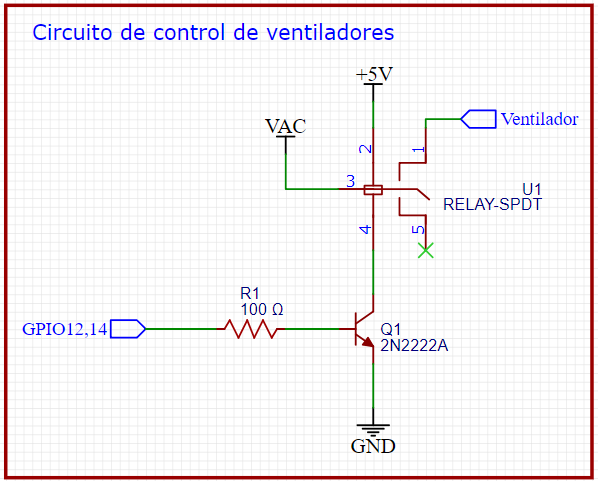
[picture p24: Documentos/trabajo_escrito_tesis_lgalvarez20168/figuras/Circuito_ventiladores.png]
	
	\caption{Circuito con resistencia calculada para control de ventiladores con relés de 5 VCC.}
	\label{fig:diag_rele}
\end{figure}

Como se observa en el diagrama, los circuitos de control del ventilador inferior y superior se conectaron a los pines de uso múltiple 12 y 14 respectivamente. 

\subsubsection{Sensores de temperatura}

En el caso de los sensores de temperatura DHT11 y DS18B20, estos se conectaron según las recomendaciones del fabricante. Para los sensores DHT11 se utilizaron resistencias de $10k$ $\Omega$ conectadas entre 5 VCC y el pin de datos. Para estos sensores, se utilizaron los pines de uso general 4 y 13 del microcontrolador. Por otro lado, en los sensores DS18B20 se utilizó una única resistencia de $4.7k$ $\Omega$ conectada entre 5 VCC y el bus de datos. Debido al uso del protocolo One-wire, se utilizó un bus de datos conectado al pin de uso general número 15.

\subsubsection{Módulo RTC y luces de crecimiento}

El módulo de reloj de tiempo real DS3231 y las luces de crecimiento presentaron la conexión más sencilla. En estos componentes, no se utilizaron resistencias adicionales. En el caso del reloj de tiempo real, este se conectó a los pines de uso general 22 y 21, los cuales corresponden a la señal SCL y SDA respectivamente. Finalmente, las luces de crecimiento se conectaron al pin número 27.

\subsection{Desarrollo de placa PCB}			% [==========MISSING==========]

\section{Construcción del sistema}

Una vez completado el proceso de diseño general, se inició la construcción física del sistema. Como primer paso, se ensambló la estantería de metal, la cual sería utilizada como estructura principal para el sistema. Este proceso se logró con la ayuda de un mazo de goma y un metro, con los cuales se fijaron las repisas de la estantería a las alturas definidas en la etapa de diseño. Adicionalmente, se modificó una de las repisas con tal de asegurar un flujo adecuado de aire dentro del sistema. Estas modificaciones se realizaron utilizando un router manual con una fresa de 0.5 pulg con el cual se crearon ranuras longitudinales en la repisa de MDF. Una vez ensamblada la estructura principal, se inició con el ensamblaje de las tuberías de distribución y crecimiento.

El ensamblaje de las tuberías de crecimiento se inició con una tubería de 3 metros de largo, con un diámetro de 2 pulg. Esta tubería se cortó en las diferentes secciones requeridas para la construcción de los canales de crecimiento y tuberías de distribución. Luego, se utilizó una broca de copa de 1.5 pulg para realizar perforaciones en los canales de crecimiento espaciados a 17.54 mm. Estos agujeros serían utilizados para contener las plantas durante el período de crecimiento. Una vez se habían recortado todas las secciones de PVC, se utilizó sellador de silicona con una pureza del 100\% para unir las piezas con los codos y uniones tipo T. Se utilizó esta silicona para asegurar que no se encontraran fugas en los canales de distribución o crecimiento. Adicionalmente, la pureza aseguró que no se encontraran contaminantes los cuales podrían interferir con las pruebas a realizar. Finalmente, se conectó una manguera flexible de 0.5 pulg de diámetro interno al inicio de los canales de distribución, la cual permitiría suministrar el agua utilizando una bomba sumergible.

\subsection{Integración de sistemas}

Una vez se contaba con la estructura principal ensamblada, se inició la instalación de los diferentes componentes eléctricos y electrónicos en el sistema. Se instaló una caja plástica de 32 litros, la cual funcionaría como sistema de almacenamiento de agua. Una vez instalado dicho contenedor, se continuó con la instalación y conexión de sensores, actuadores, y la bomba sumergible.

\subsubsection{Conexión de sensores}

Tanto los sensores de temperatura ambiental como del agua requirieron de pequeñas modificaciones para su instalación. En el caso de los sensores DHT11, se crearon cables de conexión utilizando alambres de un cable UTP. Estos se unieron a terminales de pines axiales los cuales se utilizaron para conectar los cables a cada sensor y a la placa de desarrollo. Por otro lado, los sensores DS18B20 ya contaban con cables suficientemente largos, con la excepción de uno, por lo que se soldaron pines axiales directamente a los cables de los sensores. En el caso del sensor de temperatura de agua que se encontraba más alejado de la placa de desarrollo, se utilizó cable UTP para crear las extensiones requeridas. Finalmente, el sensor de pH SEN0161 cuenta con cables con terminales de pines axiales, por lo que la conexión no requirió de modificaciones a los cables existentes.

Los sensores DHT11 se instalaron utilizando las piezas impresas en 3D mencionadas al inicio del capítulo. Se utilizaron las varillas de 0.5 pulg para fijar los anillos de los sensores, y estas se insertaron directamente en la madera de las repisas. En el caso de las sondas de temperatura de agua, se introdujeron mediante los agujeros diseñados para fijar las plantas. Estas se ubicaron en cada una de las repisas de crecimiento, asegurando tomar mediciones en el punto de inicio del flujo de agua. La tercera sonda de temperatura de agua se instaló directamente en el depósito central de agua. 

\subsubsection{Instalación de bomba de circulación de agua}

La bomba de circulación de agua utilizada se acopló a la manguera flexible utilizando una boquilla de 0.5 pulg de diámetro, la cual se insertó a presión dentro de la manguera. Se aseguró que la distancia de la bomba hacia el punto de salida de la manguera se encontrara dentro de un rango de 3.5 pies, con tal de no forzar la bomba y asegurar un flujo adecuado de agua. Finalmente, la bomba se sumergió en el agua, y se fijó utilizando ventosas al fondo del depósito plástico. Se aseguró que la conexión del cable se encontrara lo más alejada de la fuente de agua posible, para evitar fallos por corto circuito.

\subsubsection{Instalación de actuadores}

Durante las primeras fases de construcción, se instalaron los ventiladores utilizando sus bases impresas, las cuales se fijaron mediante tornillos y tuercas a los perfiles de metal de la estructura principal. Al igual que los sensores, se soldaron extensiones de cable UTP a los ventiladores, permitiendo que los cables llegaran a sus puntos de conexión en la placa de desarrollo. Adicionalmente, se cubrieron todos los empalmes utilizando cinta de aislar, con tal de evitar fallos por corto circuito. Por otro lado, las luces de crecimiento se instalaron utilizando repisas adicionales, suspendidas a una distancia de aproximadamente 150 mm de las tuberías de crecimiento. Se utilizó cable UTP para unir las diferentes secciones de tiras LED, y se colocaron conectores axiales en cada una de las secciones, asegurando así una fácil conexión entre la placa de desarrollo y las luces de crecimiento.

\begin{figure}[H]
	\centering
	
	\caption{Estructura instalada en vivero con los diferentes componentes instalados y conectados.}
	\label{fig:estructura_final}
\end{figure}

%-----------------------------------------------------------------------------------------------------------

\chapter{Programación del \textit{firmware} del sistema}

\section{Definición de protocolo de comunicación inalámbrica}

Una de las ventajas de los sistemas hidropónicos se centra en sus bajos requisitos de mano de obra y atención constante. Esta ventaja se puede capitalizar significativamente al incluir un protocolo que permita enviar los datos a un servidor para ser consultados por un operador de manera remota. En el Siglo XXI, el crecimiento de tecnologías inalámbricas han facilitado esta tarea mediante el Internet de las cosas (IoT, por sus siglas en inglés). Si bien el internet de las cosas es un concepto sumamente valioso, este no se puede aprovechar sin contar con un protocolo de comunicación de datos que habilite su acceso.

\subsection{Conexión inalámbrica mediante WiFi}

El crecimiento en popularidad del internet de las cosas se atribuye principalmente a los avances realizados en cuanto a la familia de protocolos de comunicación con fidelidad inalámbrica, más conocida como WiFi. \cite{biber} Esta familia de protocolos ofrece una gran flexibilidad en cuanto a la estructura de paquetes para el envío de datos a través de grandes distancias y de una gran variedad de dispositivos. Esta versatilidad, permite a microcontroladores y plataformas de desarrollo como el ESP-WROOM32 utilizar este protocolo de comunicación para la transferencia de datos de manera inalámbrica.

Se utilizó la librería de \textit{WiFi.h} para la conexión del ESP-WROOM32 a una red local de internet. Una de las prioridades a la hora de diseñar la conexión a internet fue asegurar que el resto del sistema de control mantuviera su funcionamiento en caso de que se perdiera conexión WiFi. Tomando esto en cuenta, se estableció un intento inicial de conexión una vez se enciende el sistema. En caso de que se haya perdido conexión, o esta no se haya establecido exitosamente, se estableció un período de espera de 30 minutos, durante los cuales el sistema no intentaría conectarse al internet. Finalizados los 30 minutos, el sistema iniciaría nuevamente su rutina para establecer dicha conexión. Esta implementación fue esencial, puesto que la rutina para conectar el sistema al internet bloquearía el código durante un período considerable de tiempo. Por esta razón, sería necesario salir de la rutina de conexión luego de cierto tiempo, antes de volver a intentar la conexión.

\subsubsection{Protocolo HTTP}

Una vez establecida la conexión WiFi, se habilitó la comunicación con el servidro de Dweet.io mediante el protocolo HTTP. Puesto que la comunicación HTTP consiste de una solicitud enviada a un servidor, esta no requiere establecer una conexión como tal. Por esta razón, se programó una función a cargo de envíos de datos al servidor, iniciando la solicitud en el momento deseado, y finalizando una vez se recibió una respuesta adecuada del servidor. Debido a que una interrupción en el envío de datos podría resultar en un error, se estableció una cantidad de intentos máxima, para asegurar que los datos fuesen enviados, o que se regresara al ciclo principal en caso de no lograr la comunicación. Al igual que la función para la conexión a la red WiFi, la comunicación HTTP bloqueaba el código durante un tiempo significativo, por lo que estas medidas de seguridad se consideraron justificables.

Durante cada conexión al servidor, se enviaron dos paquetes de información, uno a la dirección \textit{hydro\_test} y otro a la dirección \textit{hydro\_LOG}. El primero de estos paquetes consistió de datos de los sensores, estados de los actuadores, e información de la fecha y hora del reloj de tiempo real del sistema. Esta información sería procesada por la aplicación con tal de monitorear los parámetros dentro del sistema de crecimiento. El segundo de los paquetes consistió de información acerca del estado de la conexión, detallando el nombre de la red a la que se encuentra conectado el sistema, así como la intensidad de la señal, la fecha y hora, y un contador de la cantidad de veces que falló el envío de datos al servidor antes del envío actual. Es importante mencionar que la información en ambos paquetes se configuró utilizando el formato JSON, el cual establece un objeto compuesto por un conjunto de propiedades, a las cuales se les asigna un valor según sea necesario. En este caso, se utilizó el formato JSON para establecer propiedades de temperatura, humedad, y otros parámetros los cuales se unieron con los valores recolectados por los sensores.

\section{Configuración de sensores y accionamiento de actuadores}

El proceso de configuración de los sensores de temperatura y humedad, así como las sondas de temperatura del agua, se completó sin mayor dificultad. Esto pues, la simplicidad en el funcionamiento de estos sensores eliminó los requerimientos de calibración. Los valores obtenidos de estos sensores se compararon con límites preestablecido, con tal de definir una secuencia de control sencilla para los ventiladores. Esto se implementó con tal de asegurar que tanto la temperatura como la humedad ambiental se mantuvieran en un rango adecuado para el crecimiento de las plantas. Por otro lado, los datos recolectados de las sondas de temperatura se almacenaron para ser enviadas al servidor de Dweet.io para su monitoreo.

En el caso de los actuadores, se establecieron funciones de control para los ventiladores y las luces de crecimiento respectivamente. En el caso de la función para la activación de los ventiladores, esta se enfocó en activar los pines transistorizados para cada ventilador, y cambiar el estado de banderas específicas con tal de comunicar el estado de los ventiladores al operador. Ahora bien, el control de las luces de crecimiento presentó una mayor cantidad de retos. Si bien la función diseñada para encender y apagar las luces de crecimiento no presentó grandes obstáculos, permitiendo cambiar el color de cada luz de manera individual y encender las luces a intervalos establecidos, se dificultó el registro del tiempo. Debido a los requerimientos de luz de las plantas, las luces de crecimiento deberían permanecer encendidas durante un período determinado. Ahora bien, se debería mantener un punto de referencia, con el cual se podría establecer cuánto tiempo han estado encendidas las luces, y cuanto tiempo más deberían estar apagadas, aún cuando el sistema de control perdiera alimentación. Por esta razón, se introdujo el módulo RTC, el cual aseguraría que las luces se encendieran siempre a la hora configurada, y se apagaran a la hora deseada. Durante la configuración del módulo RTC, se incluyó una rutina para sincronizar el tiempo del reloj interno con el tiempo del servidor de Dweet.io en caso de que el módulo perdiera poder. Estas medidas aseguraron que el tiempo del sistema se mantuviera de acuerdo con el tiempo real de la ubicación del sistema.

%------------------------------------------------------------------------------------------------------------

\chapter{Desarrollo de aplicación móvil}

\section{Requisitos de funcionalidad}

La aplicación móvil presenta una oportunidad de desarrollar una interfaz demostrativa, que sea capaz de brindar información al usuario de manera legible. Por esta razón, se establecieron diferentes requisitos de funcionalidad. Uno de estos, consistió en la conexión de la aplicación a internet para establecer una comunicación con el servidor de Dweet.io y obtener los datos del sistema. Otro de los requisitos de funcionalidad se centró en contar con una interfaz fácil de leer, que desplegara los datos recolectados por los sensores al usuario de una manera sencilla. De la mano con este requisito, se estableció que el usuario no fuese capaz de ingresar datos en las casillas que desplegaran los datos de los sensores. Finalmente, se buscó que la interfaz contara con un botón que permitiera al usuario refrescar los datos con tal de asegurar que la lectura más actualizada de los sensores se estuviese desplegando en la interfaz. 

\subsection{Diseño de interfaz gráfica}

El diseño de la interfaz gráfica se llevó a cabo utilizando el lenguaje de marcado extensible XML. Dentro del entorno de programación del estudio de \textit{Android}, se definieron dos pantallas. Una de estas presentaría el logo de la aplicación, así como el nombre, mientras que la segunda contaría con la información de los sensores del sistema. Se desarrolló el logo de la aplicación utilizando la herramienta gratuita de \textit{Canva}, y se utilizaron las herramientas de \textit{Android} para importar las imágenes utilizadas en la aplicación. Una vez se definieron las pantallas, sus estructuras y sus componentes, se continuó con la programación del funcionamiento de la aplicación.

\begin{figure}[H]
	\centering
	
	\caption{a) Pantalla de inicio de la aplicación. b) Interfaz gráfica principal.}
	\label{fig:interfaz_graf}
\end{figure}

\subsection{Lectura de datos de servidor HTTP}

Se utilizó el protocolo HTTP para obtener los datos del servidor Dweet.io bajo la dirección de \textit{hydro\_test}. Dentro de la función de lectura de datos del servidor, se obtuvieron los valores de las categorías del objeto JSON, y se asignaron a variables las cuales serán utilizadas para actualizar las casillas respectivas en la interfaz. Adicionalmente, se estableció un ciclo de lectura continuo, el cual realizaría una solicitud de información al servidor cada 5 minutos, e iniciaría un segundo después de acceder a la interfaz. Finalmente, se incluyó una función que ejecutaría una solicitud al servidor en el caso de que se presionara el botón para refrescar los datos.

\subsection{Notificaciones}					% [==========MISSING==========]

%-------------------------------------------------------------------------------------------------------------

\chapter{Evaluación del crecimiento del cilantro}

\section{Cultivo del cilantro en sustrato nutritivo}

Con tal de evaluar el crecimiento del cilantro, se inició un cultivo utilizando un sustrato activo. Este cultivo funcionaría como punto de comparación, permitiendo identificar cambios en el crecimiento del cilantro dentro del sistema. Con tal de lograr el crecimiento adecuado de las plantas de cilantro, se estableció un sustrato que fuese capaz de cumplir con las siguientes características: alta retención de humedad, baja densidad permitiendo oxigenación y un alto contenido nutritivo. Con estas características en mente, se realizó una mezcla de vermiculita, \textit{peat-moss}, tierra abonada y compost orgánico. Esta mezcla permitió contar con una buena retención de agua gracias a la vermiculita, un nivel bajo de densidad debido al \textit{peat-moss}, y una alta cantidad de nutrientes. Una vez se preparó el sustrato de crecimiento, se repartió en diferentes contenedores, los cuales permitirían el desarrollo de las plantas asegurando una distancia de 180 mm entre planta. 

\subsection{Período de germinación del cilantro}

Con tal de establecer una línea base de crecimiento, se inició un grupo de plantas de cilantro desde la semilla. Para esto, se emplearon dos metodologías de germinación. En la primera, como se observa en la Figura \ref{fig:ziplock} se utilizó una bolsa resellable, en la cual se introdujo una toalla de papel húmeda con semillas de cilantro. Esta bolsa se almacenó en un ambiente oscuro y a una temperatura constante cercana a los 25 °C. Como segundo método, se utilizó un sustrato inerte, el cual consistió en una mezcla de \textit{peat-moss}, vermiculita y fibra de coco como sustrato de germinación. 

\begin{figure}[H]
	\centering
	
	\caption{Semillas germinadas utilizando papel toalla y bolsa resellable.}
	\label{fig:ziplock}
\end{figure}

\begin{figure}[H]
	\centering
	
	\caption{Semillas germinadas utilizando sustrato mecánico inerte.}
	\label{fig:peatmoss}
\end{figure}

Tanto las semillas en la bolsa resellable como las del sustrato inerte presentaron desarrollo de raíces luego de 8 días en condiciones óptimas. Es importante mencionar que si bien el sustrato inerte fue capaz de mantener un nivel de humedad aceptable, fue necesario regar dicho sistema de manera periódica durante el tiempo de germinación. Por otro lado, las semillas dentro de la bolsa resellable nunca presentaron pérdidas significativas de humedad, por lo que no fue necesario hidratarlas más de una vez. A parte de la diferencia en retención de humedad, no se observó una diferencia significativa entre ambos métodos de germinación en cuanto al tiempo o eficiencia. 

\subsection{Retos en el desarrollo de retoños}

Una vez se observó el desarrollo de raíces en los retoños, estos se trasladaron a un sustrato compuesto principalmente por \textit{peat-moss}, vermiculita y tierra abonada. Es importante resaltar que durante las primeras semanas de desarrollo, los retoños no recibieron una cantidad adecuada de luz, por lo que se presentó un fenómeno conocido como \textit{bolting} o espigado. Este proceso llevó al desarrollo de tallos largos y débiles, lo cual llegó a representar un reto significativo en futuras etapas del desarrollo. Adicionalmente, durante las primeras semanas de crecimiento, se utilizó una proporción menor de compost, lo cual redujo la cantidad de nutrientes disponibles para los retoños.

\subsection{Transplante de retoños a sustrato nutritivo de crecimiento}

Los retos mencionados anteriormente se corrigieron luego de transplantar los retoños al sustrato nutritivo, sin embargo, la mayoría de los retoños contaban con un tallo principal considerablemente largo y débil. Por esta razón, se sembraron los retoños a una mayor profundidad, buscando evitar la pérdida de retoños por daños al tallo. Mientras que este proceso ayudó a que la mayoría de los retoños se continuaran desarrollando, la exposición a los elementos como la lluvia y el viento inevitablemente dobló algunos de los retoños, llevando a pérdidas por falta de circulación de nutrientes a través de los tallos. En la Figura \ref{fig:transplante_plantas}, se observa la configuración de los retoños en las macetas, y se acortó la altura de los tallos al sembrarlos a mayor profundidad. Finalmente, es importante mencionar que durante el proceso de transplante, se descartaron aquellos retoños que se habían vencido sobre su propio peso, así como retoños que no habían desarrollado suficientemente sus raíces como para absorber nutrientes del sustrato.

\begin{figure}[H]
	\centering
	
	\caption{Configuración de los retoños luego de ser transplantados a sustrato nutritivo de crecimiento.}
	\label{fig:transplante_plantas}
\end{figure}

\section{Cultivo de cilantro en sistema hidropónico}

Luego de las primeras 4 semanas del desarrollo del cilantro en sustrato de crecimiento, se trasladaron 12 plantas de cilantro al sistema hidropónico. Se colocó una planta por espacio disponible en los canales de crecimiento, y se reguló la concentración de solución nutritiva, diluyendo 2.5 mL de macro y micro nutrientes por galón de agua en el sistema. Ahora bien, cabe mencionar que en el momento en que se trasladaron las plantas de cilantro, aún no se contaba con un control adecuado de temperatura ambiente. Adicionalmente, como se observa en la Figura \ref{fig:estructura_final}, el sistema tampoco contaba con un control de luz de crecimiento, estando abierto aún a la luz ambiental.

\subsection{Elementos de soporte para las plantas}

En un sustrato activo, este provee tanto los nutrientes necesarios para el crecimiento de las plantas, como la estabilidad mecánica para asegurar que estas se mantengan erguidas. Ahora bien, en un sistema hidropónico, las plantas no cuentan con este sustrato, por lo cual es necesario utilizar otros métodos para brindar estabilidad mecánica a las plantas. Durante las pruebas iniciales, se utilizaron pedazos de tubo flotador, los cuales se cortaron de manera que fuesen capaces de ingresar en los agujeros disponibles en los canales de crecimiento. Además, se aseguró que estos fueran capaces de apoyar a las plantas, asegurando que se mantuvieran en su lugar. Ahora bien, cabe mencionar que estos tubos flotadores están elaborados de un material sintético el cual absorbe e irradia calor con facilidad. Esto no habría sido un gran problema en un sistema hidropónico sumergible, sin embargo, al utilizar la metodología NFT, este material no contó con una manera de liberar su calor.

Mientras se realizaron pruebas iniciales de crecimiento, se observó una temperatura máxima en el sistema alrededor de los 32 °C, la cual fue considerablemente mayor a la temperatura máxima del cilantro, alrededor de los 25 °C. Este aumento en temperatura elevó el consumo de agua de las plantas, resultando en una acumulación de sales en las raíces, como se observa en la Figura \ref{fig:raices}. Esta acumulación de sales, junto a las elevadas temperaturas en los pedazos de tubo flotante, llevaron a la pérdida del 66\% de las plantas en el sistema hidropónico.

\begin{figure}[H]
	\centering
	
	\caption{Retoño de cilantro con tallo seco y raíces bloqueadas por sales de la solución nutritiva.}
	\label{fig:raices}
\end{figure}

\section{Retos en el cultivo del cilantro durante períodos de prueba}	% [==========MISSING==========]

\section{Comparaciones del crecimiento del cilantro}	% [==========MISSING==========]

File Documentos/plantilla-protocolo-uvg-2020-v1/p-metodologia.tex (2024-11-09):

\subsection*{Definición de línea base de crecimiento del cilantro}
Es importante cultivar una muestra de cilantro empleando una técnica de crecimiento tradicional con sustrato nutritivo con tal de comparar el rendimiento del cilantro hidropónico cultivado en el sistema propuesto. El cultivo de control o de línea base se realizará utilizando un sustrato definido en un período de tiempo preestablecido. Al finalizar el período de crecimiento del cultivo, se realizará una cosecha del cilantro durante la cual se realizarán mediciones de sus características físicas. Entre estas se incluirá el peso húmedo de la planta (esencialmente el peso de la planta incluyendo raíces y tallo principal), la cantidad de hojas presentes, y su altura total desde la base del tallo principal. Estos parámetros se registrarán para realizar una comparación cuantitativa y cualitativa del cilantro hidropónico versus el cilantro cultivado en sustrato nutritivo.

Tanto el cultivo de cilantro en sustrato nutritivo como en el sistema hidropónico se iniciarán desde la semilla en un sustrato de germinación. Se utilizarán semillas de la tienda Hidroponía Guatemala, las cuales se germinarán en una toalla de papel húmeda resguardada en una bolsa \textit{zip-lock}. En el caso del sustrato nutritivo, se iniciarán 10 semillas, de las cuales se seleccionarán 5 brotes para ser cultivados en un área designada. Luego de un período de una semana, se revisarán las semillas para seleccionar las que hayan germinado y trasplantarlas a un sustrato de incubación. Este consistirá en una mezcla de compost orgánico, perlita, y fibra de coco fina. Adicionalmente, se agregará canela en polvo a la mezcla para reducir la probabilidad de crecimiento de hongos o moho en las semillas o raíces. Una vez que los retoños hayan alcanzado una altura aproximada de cinco centímetros, se  revisarán las raíces para determinar si estas se han desarrollado lo suficiente para ser trasplantadas. En caso de que el crecimiento sea satisfactorio, se trasplantarán a un área de cultivo con un espacio entre plantas de 150 mm. 

El sustrato de cultivo consistirá de una mezcla de arena de río, tierra negra, abono orgánico y fibra de coco. Al igual que en el sustrato de crecimiento, se agregará canela en polvo para reducir la probabilidad del desarrollo de hongos o moho en las raíces. Se realizará un monitoreo diario de las plantas con un riego del sustrato cada segundo día de ser necesario. Se definirá un período de crecimiento de 55 días, durante el cual se tomarán medidas preventivas para evitar plagas como el uso de pesticidas orgánicos. Al finalizar dicho período, se realizará la cosecha del cilantro, retirando el mismo de raíz. Antes de realizar el pesado se lavarán cuidadosamente las plantas, particularmente las raíces, para eliminar restos de sustrato o piedras.

Se registrará el peso del cilantro cosechado incluyendo las raíces con tal de obtener el peso húmedo de la cosecha. Este peso se obtendrá mediante escalas de precisión para considerar leves variaciones en el peso entre plantas. Adicionalmente, se registrará la longitud de las raíces, la altura total del cilantro desde la base del tallo principal, y se realizará un recuento de las hojas para determinar su densidad. Este proceso se realizará para cada una de las cinco plantas sembradas y se almacenarán los datos para ser comparados luego de obtener los resultados de las pruebas con el sistema hidropónico automático.

\subsection*{Construcción del sistema hidropónico}
El sistema hidropónico consistirá en tres etapas o módulos los cuales serán integrados para obtener las condiciones de crecimiento deseadas y el control de parámetros. Estos módulos cumplen diferentes funcionalidades, desde proporcionar una estructura estable al sistema hasta realizar las mediciones y el control de parámetros. La construcción del sistema hidropónico requerirá de la integración de estos módulos para su funcionamiento adecuado.

\subsubsection{Estructura física principal}
Esta estructura consistirá en una estantería de metal con repisas fijadas a una distancia aproximada de 400 mm entre sí. Estas repisas cumplirán la función de proporcionar una base estable para colocar los canales de crecimiento y los sensores del sistema. Adicionalmente, las repisas proveerán una superficie en la cual se colocaran las luces de crecimiento. Con tal de facilitar el proceso de construcción, se utilizará una repisa prefabricada de metal y madera, la cual cuenta con alturas de repisas ajustables. El metal con protección ambiental reducirá los posibles daños por corrosión, y la madera provee una plataforma flexible sobre la cual se pueden montar los diferentes elementos del sistema. En la Figura \ref{figmesh:1} se puede apreciar la estructura principal.

Si bien basta con la estantería para soportar el sistema hidropónico vertical, esta deberá ser cubierta con tal de permitir un control más cercano de los niveles de luz en el sistema así como de la temperatura ambiente y humedad. Se utilizará un nailon negro en pliegos para recubrir la estructura, utilizando acoples para tensar el material y lograr una cubertura adecuada. Adicionalmente, se agregarán dos agujeros para incluir ventiladores en la estructura, los cuales proveerán una circulación de aire y serán empleados para controlar la temperatura y humedad interna.

\subsubsection{Distribución de solución nutritiva}
El sistema de distribución de nutrientes consistirá en una serie de tuberías de PVC las cuales distribuirán la solución nutritiva desde un depósito en la base del sistema hacia todas las repisas de crecimiento. Se utilizarán tuberías de PCV con un diámetro de 3 pulgadas colocados a 150 mm entre centros. Estas almacenarán las plantas, por lo que tendrán un agujero de 2 pulgadas de diámetro en el cual se colocarán las canastas de crecimiento. Adicionalmente, estas estarán inclinadas a un ángulo adecuado para facilitar la caída del agua de una repisa hacia otra. Esta inclinación se logrará mediante soportes impresos con filamento de impresión 3D para asegurar que las tuberías se mantengan fijas en la inclinación deseada. 

Los canales de crecimiento serán alimentados con solución nutritiva mediante un sistema de tuberías de PVC de $1/4$ de pulgada. Se utilizará una tubería principal a la cual se conectará una bomba de agua sumergible, y llevará la solución nutritiva hacia la repisa superior del sistema. Luego, se realizarán conexiones entre repisas utilizando tuberías del mismo diámetro para asegurar un flujo constante. Finalmente, la solución regresará al depósito inicial, el cual consistirá en una caja plástica. En esta se almacenará la solución nutritiva junto con los diferentes sensores y actuadores para controlar los parámetros de la solución nutritiva. Es importante mencionar que se permitirá una caída de por lo menos 150 mm para la solución que regresa al depósito, esto con tal de fomentar la agitación y oxigenación de la solución.

\subsubsection{Estructura de monitoreo y control}
Dentro del sistema hidropónico se estarán realizando mediciones de nivel de pH del agua, conductividad eléctrica de la solución, su temperatura, y la humedad y temperatura ambiente. La información de estos sensores será recolectada por un microcontrolador \textit{ESP WROOM32} el cual contendrá las funciones necesarias para la lógica de control y el accionamiento de los actuadores. Adicionalmente, permitirá la conectividad del sistema con la red inalámbrica para el monitoreo externo de parámetros desde una aplicación móvil. Estos sensores y el microcontrolador requerirán de un espacio en donde se puedan resguardar del agua y la humedad inherentes del sistema. Si bien, los sensores que se encontrarán en contacto directo con el agua están diseñados para ello, los demás componentes como la fuente de poder las placas de control no están diseñadas para resistir altos niveles de humedad. Por esta razón, se diseñará un contenedor dedicado y hermético para resguardar los componentes eléctricos de importancia.

El contenedor deberá ser capaz de almacenar una fuente de alimentación conmutada, la cual será utilizada para suministrar el voltaje requerido por los componentes del sistema. Adicionalmente, deberá admitir una conexión eléctrica general de 120VAC, la cual será el suministro de energía eléctrica para el sistema. Con tal de facilitar el diseño y la construcción del sistema, se evaluará el uso de un contenedor plástico prefabricado el cual cuente con un cierre hermético o sea fácil de sellar. Se utilizará silicona resistente al agua para rellenar cualquier abertura requerida para cables, y empaques en donde sea necesario. Adicionalmente, contará con un toma corrientes estándar para el suministro de energía eléctrica al sistema. Es importante mencionar que se deberán realizar cálculos de voltaje para asegurar que los cables utilizados en las etapas de potencia sean del calibre adecuado según las cargas esperadas. Finalmente, se diseñarán enganches requeridos para fijar los diferentes sensores en las ubicaciones deseadas alrededor del sistema hidropónico, los cuales serán impresos en 3D para reducir costos y tiempos de producción.

\subsection*{Programación del sistema embedido}
Tanto el control de los actuadores como la lectura de los sensores requerirá del uso de un microcontrolador. Considerando que se estará empleando el \textit{ESP WROOM32}, este se programará utilizando la plataforma de desarrollo de \textit{Arduino}. La programación del sistema embedido se dividirá en múltiples fases las cuales abarcan la programación de la comunicación inalámbrica para el envío y la recepción de datos de la nube, la lectura de sensores, los cálculos de control requeridos para estabilizar niveles deseados, y la programación de los actuadores. Cada una de estas etapas contará con pruebas a realizar, las cuales incluyen pruebas de conectividad y del funcionamiento correcto de sensores y actuadores.

\subsubsection{Conectividad a \textit{Dweet.io} mediante HTTP}
La ventaja de utilizar el sistema de \textit{Dweet.io} es que permite el uso de solicitudes mediante el protocolo HTTP. Esto aumenta la velocidad de la transmisión de datos al reducir la necesidad de establecer la conexión a un servidor predeterminado. Por otro lado, esto permite el desarrollo de dos funciones de comunicación dedicadas a solicitar y publicar información al servidor de \textit{Dweet.io}. Es importante establecer que una transferencia adecuada de datos se definirá como una transferencia sin pérdida de información, y que mantenga el orden estructural de los datos para facilitar su recuperación.
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

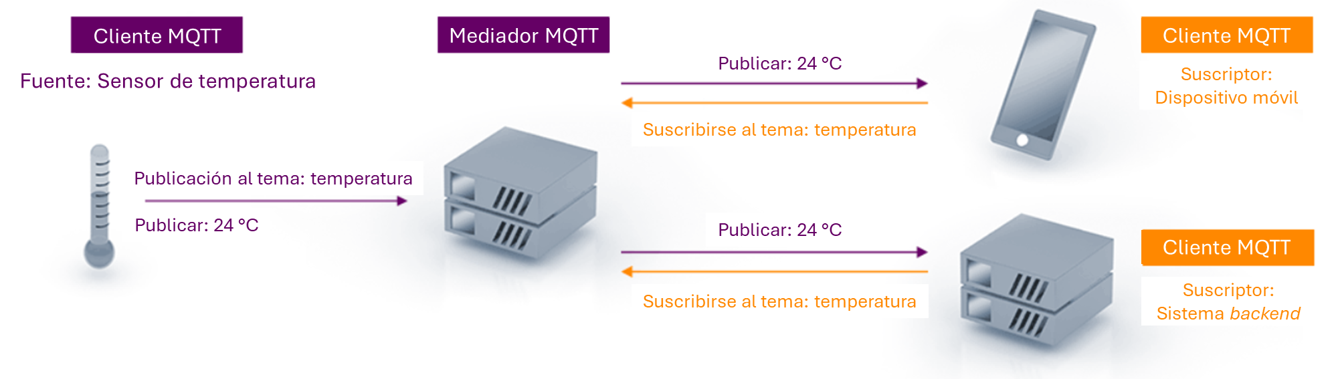
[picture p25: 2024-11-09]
Documentos/trabajo_escrito_tesis_lgalvarez20168/figuras/Figura_14_protocolo_mqtt.png

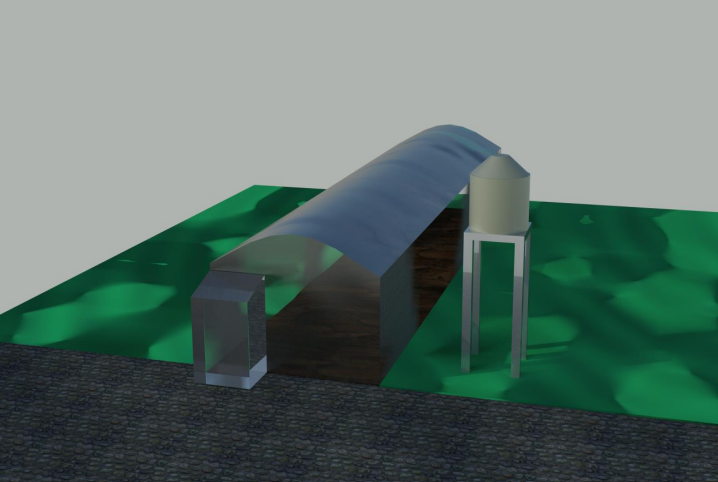
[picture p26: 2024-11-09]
Documentos/trabajo_escrito_tesis_lgalvarez20168/figuras/Figura1_modelo3D_invernadero_gonzalez.png

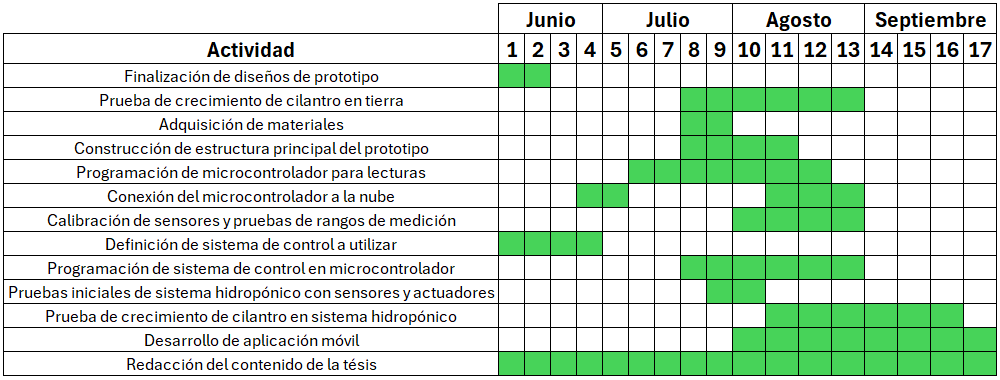
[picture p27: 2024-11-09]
Documentos/trabajo_escrito_tesis_lgalvarez20168/figuras/Cronograma_actividades1.png

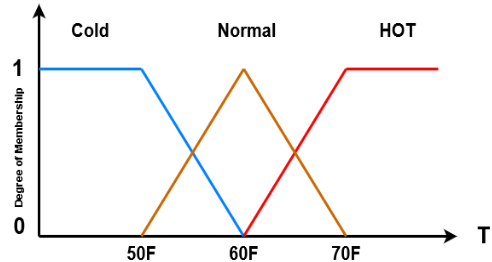
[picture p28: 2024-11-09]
Documentos/trabajo_escrito_tesis_lgalvarez20168/figuras/Figura4_funcion-membresia-fuzzy-logic.png

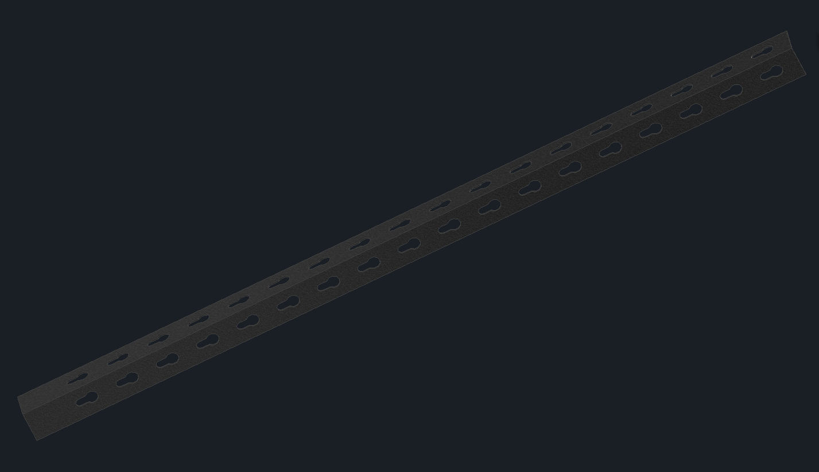
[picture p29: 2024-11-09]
Documentos/trabajo_escrito_tesis_lgalvarez20168/figuras/Perfil_slotted.png

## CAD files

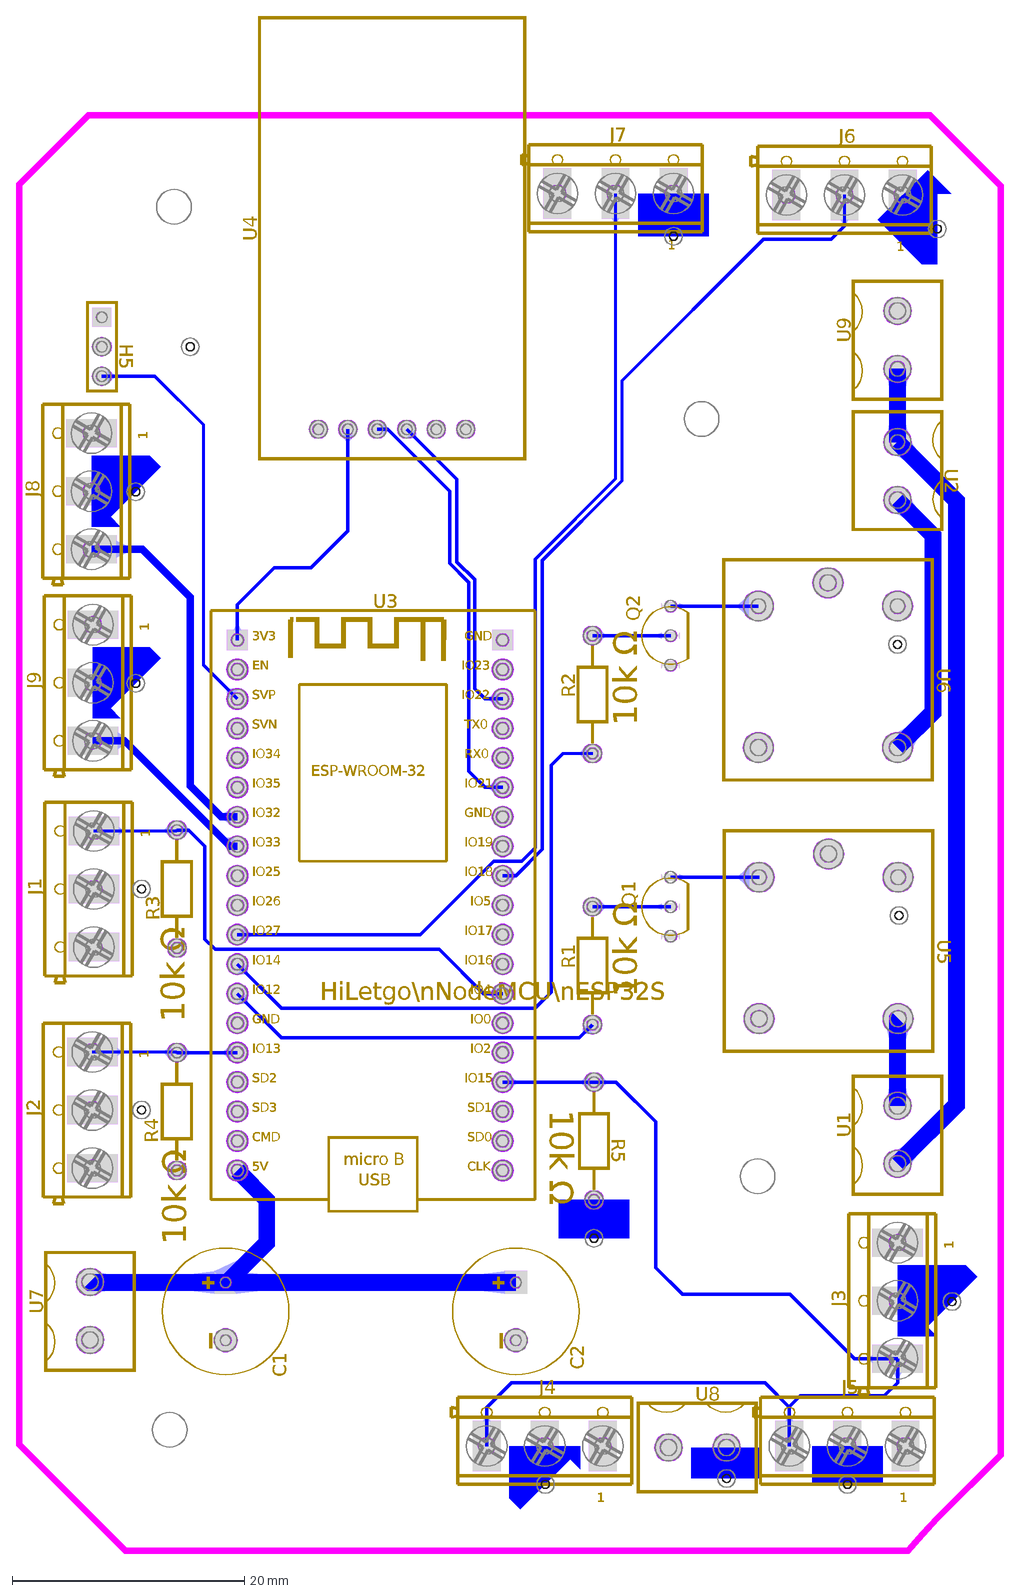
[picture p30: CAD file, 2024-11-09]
Desarrollo PCB/PCB_Tesis_v2_2024.dxf
H5
C1
C2
J1
1
J2
J3
J4
J5
J6
J7
J8
J9
Q1
Q2
R1
10k Ω
R2
R3
R4
R5
U1
U2
U3
SD2
USB
micro B
ESP-WROOM-32
IO13
GND
IO12
IO14
IO27
IO26
IO25
IO33
IO32
IO35
IO34
SVN
SVP
RX0
IO15
IO2
IO0
IO4
IO16
IO17
IO5
IO18
IO19
IO21
TX0
IO22
IO23
EN
SD1
SD0
3V3
SD3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

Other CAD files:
Modelos CAD/TH_acople_servo_valvula.ipt
Modelos CAD/TH_fan_holder.ipt

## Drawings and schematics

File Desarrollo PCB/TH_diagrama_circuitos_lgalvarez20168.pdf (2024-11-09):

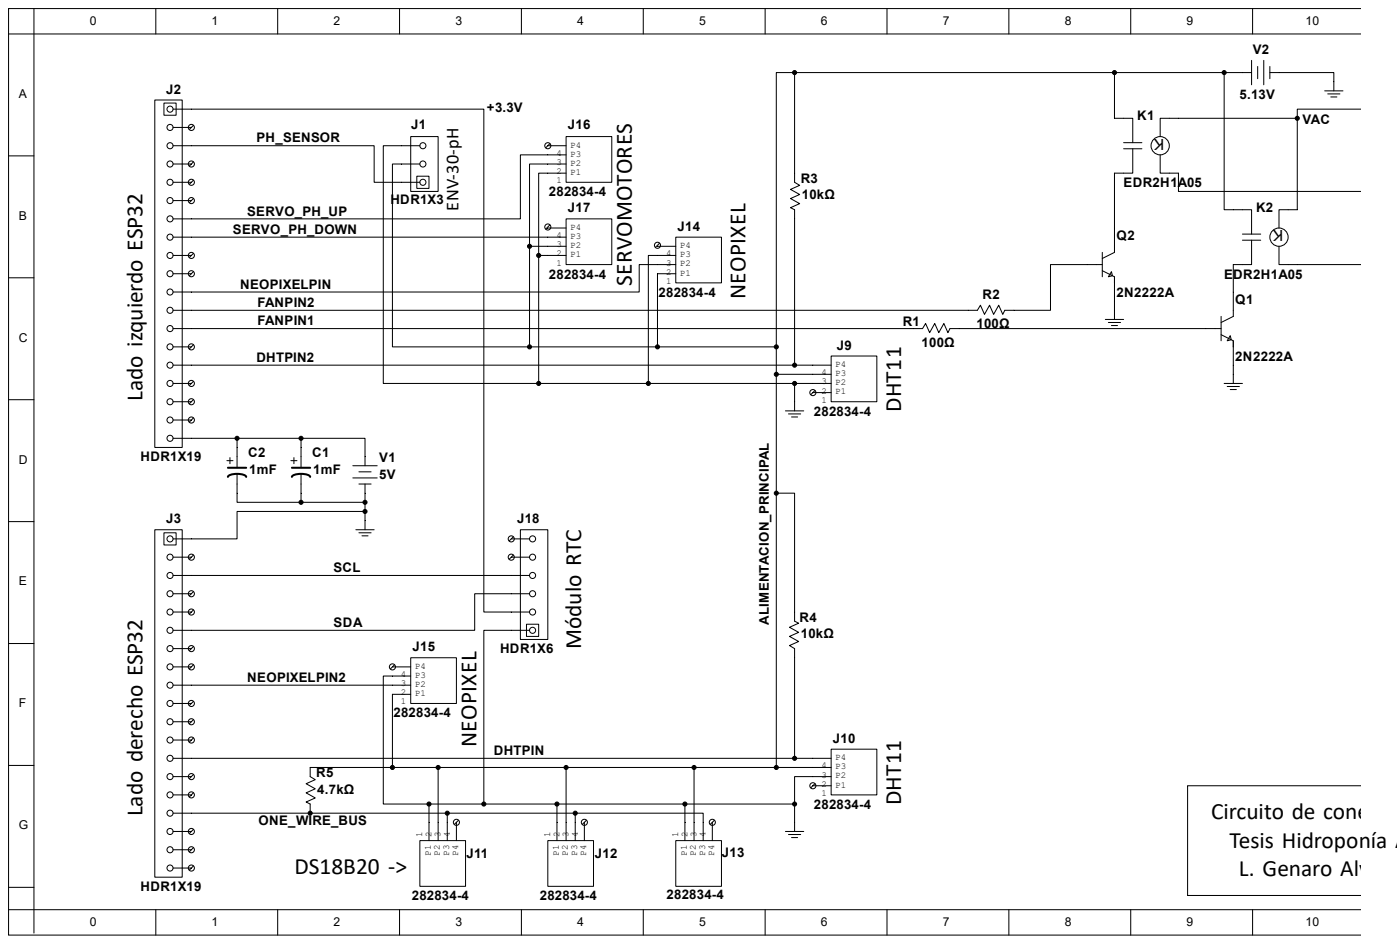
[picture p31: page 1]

Circuito de conexiones placa de control
Tesis Hidroponía Automá
L. Genaro Alvarez Sulecio (20168)

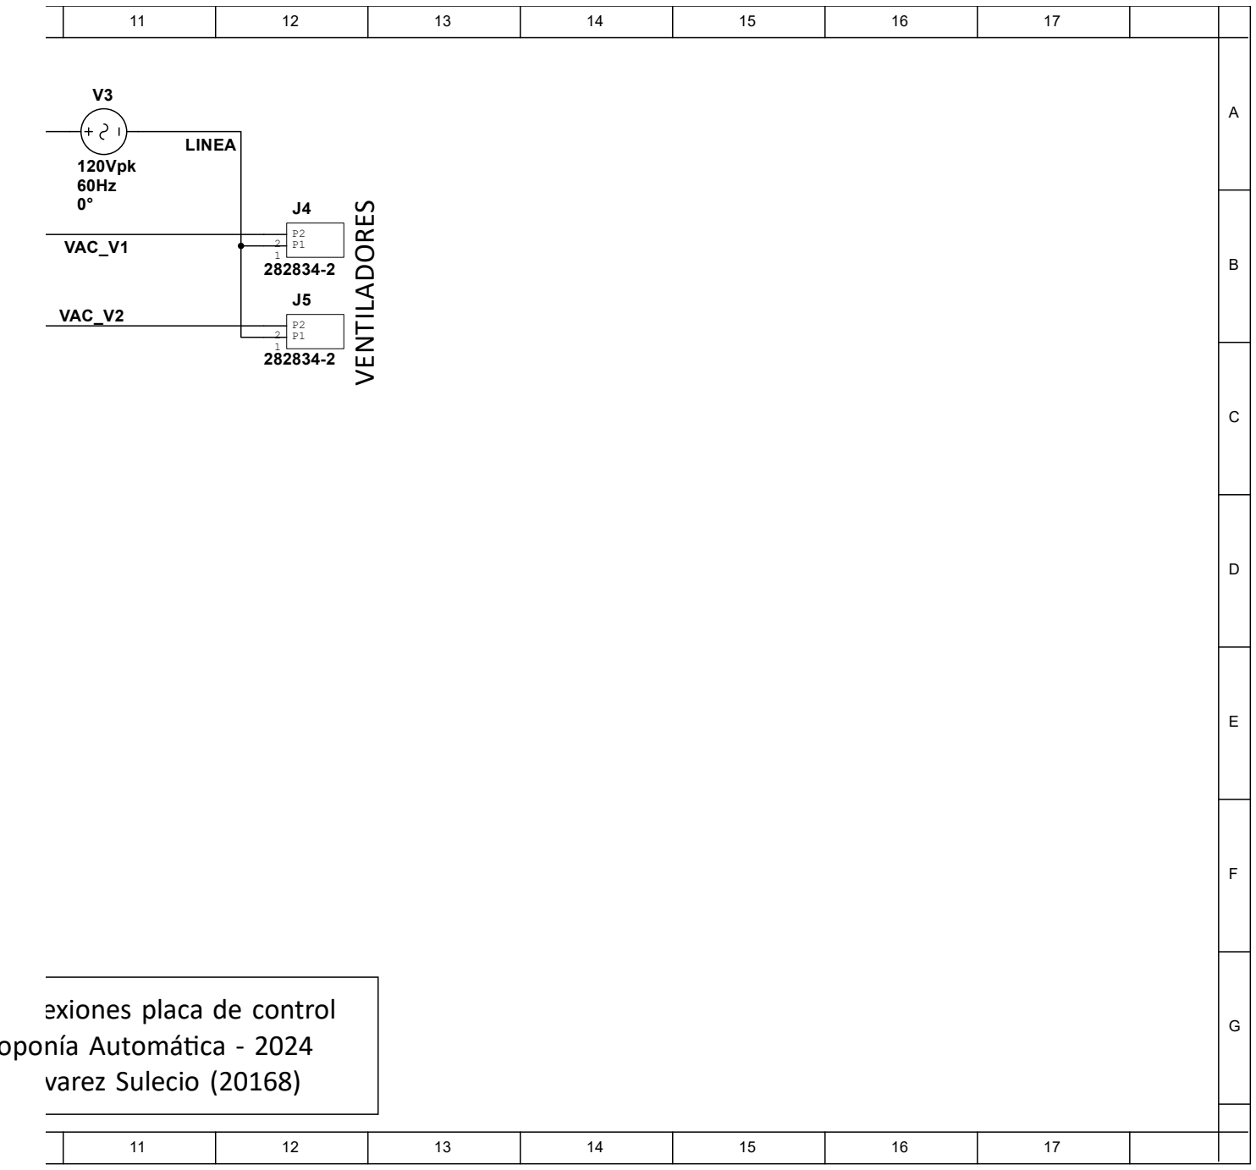
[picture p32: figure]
120Vpk 60Hz 0°; VAC_V2; VAC_V1; LINEA; VENTILADORES; Tesis Hidroponía Automáca - 2024

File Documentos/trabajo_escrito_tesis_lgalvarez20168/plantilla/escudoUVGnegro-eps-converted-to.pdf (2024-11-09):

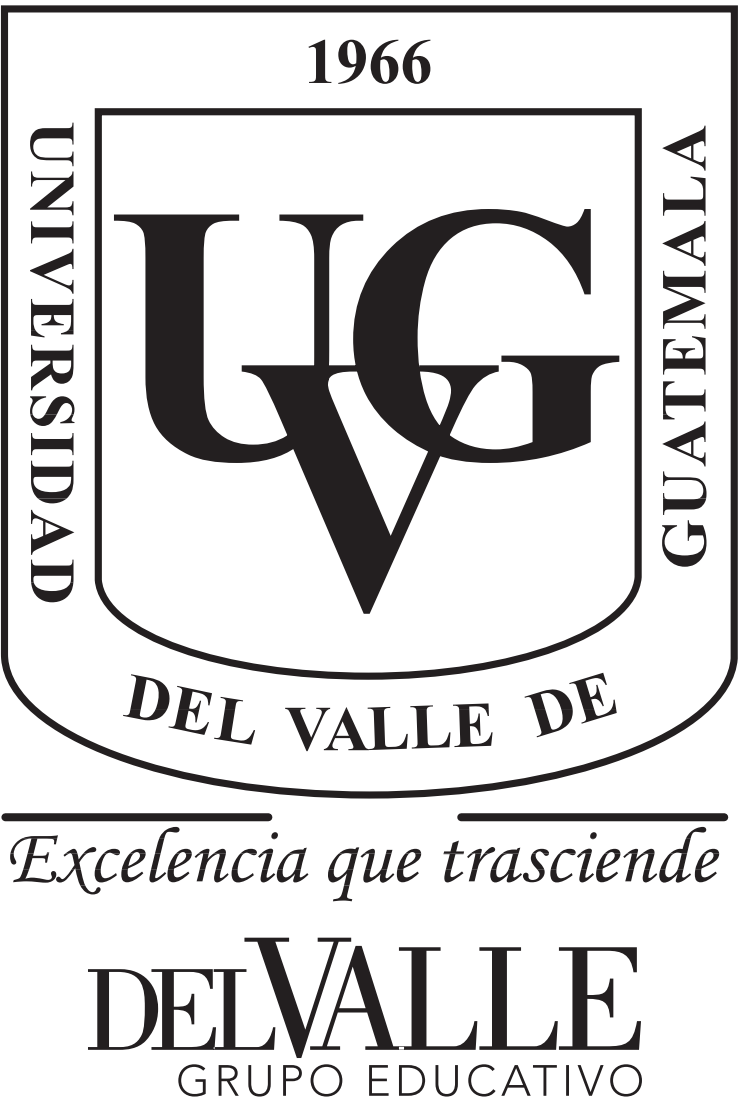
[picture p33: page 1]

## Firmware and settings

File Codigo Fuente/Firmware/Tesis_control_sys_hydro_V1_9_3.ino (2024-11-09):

/*  Version 1.9.3
    Autor: Ing. Luis Genaro Alvarez Sulecio
    Tesis de sistema hidroponico automatico
    Comentarios: 
    - Limpieza de codigo eliminando lineas de prueba, variables obsoletas,
      funciones descontinuadas y completando la documentacion del codigo.
*/
//---------------------Librerias utilizadas---------------------------
//#define USE_PULSE_OUT
#include <WiFi.h>               // Libreria para conexion wifi
#include <WiFiMulti.h>          // Libreria para gestionar multiples redes WiFi
#include <ArduinoHttpClient.h>  // Librería de arduino para conexiones HTTP > https://github.com/arduino-libraries/ArduinoHttpClient/blob/master/README.md
#include <String.h>             // Formato de informacion en tipo String
#include <ArduinoJson.h>        // Formato de informacion en tipo JSON para envio por HTTP
#include <DHT.h>                // Lectura de sensores DHT11
#include <OneWire.h>            // Protocolo de comunicacion de datos OneWire, utilizada para sensores DS18B20
#include <DallasTemperature.h>  // Lectura de sensores DS18B20, procesamiento de datos recividos
#include <Adafruit_NeoPixel.h>  // Control de luces de crecimiento (neopixeles WS2812)
#include <Wire.h>               // Comunicacion I2C con modulo RTC
#include <RTClib.h>             // Formateo de datos recibidos del modulo RTC: https://learn.adafruit.com/metro-minimalist-clock/code-it
#include <ESP32Servo.h>         // Control de servomotores utilizando pines PWM del ESP 32

// Recoleccion de datos de sensor de pH de Atlas Scientific
#ifdef USE_PULSE_OUT
  #include "ph_iso_surveyor.h"  // Libreria a utilizar si se emplea salia digital del modulo de filtrado de ruido
  Surveyor_pH_Isolated pH = Surveyor_pH_Isolated(A0);         
#else
  #include "ph_surveyor.h"      // Libreria para lectura analogica de sensor de pH
  Surveyor_pH pH = Surveyor_pH(A0);   
#endif

//----------------Definiciones de pines-------------
#define DHTPIN 4                // Resistencia pull-up de 10k Ohms (5V a datos)
#define DHTPIN2 13              //          ||          ||
#define DHTTYPE DHT11           // Tipo de sensor DHT instalado (entre DHT11 y DHT22)
#define ONE_WIRE_BUS 15         // Resistencia pull-up de 4.7k Ohms (5V a datos)
#define FAN1PIN 12              // Resistencia de 100 Ohms a pin colector de 2N2222A
#define FAN2PIN 14              //    ||          ||               ||        ||
#define NEOPIXELPIN 27          // Pin de control de luces neopixel (agregar pin 18 o 19 para control individual de cada nivel de luces)
#define NEOPIXELPIN2 18         //    ||                ||
#define SERVO_PH_UP 32          // Pin para control de servomotor para aumentar pH
#define SERVO_PH_DOWN 33        //    ||                ||          || disminuir pH

//--------------Definiciones constantes---------------
#define ACTIVE 1                // Estado activo (ventiladores)
#define IDLE 0                  // Estado inactivo     ||
#define DS18_PRECISION 9        // Presicion de sensores DS18B20
#define NUM_PIXELS 60           // Cantidad de luces led en tira NeoPixel (122 en sistema completo)
#define HTTP_TIMEOUT 5000       // Tiempo de espera para respuesta de servidor HTTP
#define HTTP_MAX_RETRY 3        // Cantidad maxima de intentos para envio de datos por HTTP
#define JSON_BUFFER_SIZE 256    // Tamano del buffer para empaquetado de datos en formato JSON
#define GLOBAL_PERIOD 30000     // Periodo de evaluacion de variables global de 30 segundos
#define TIME_24_HOUR true       // Configuracion de RTC en formato de 24H
#define OPEN 35                 // Valor de grados para abrir valvula de control de pH
#define CLOSE 0                 // Valor de grados para cerrar valvula de control de pH

//------------Structs--------------
// Struct para crear temporizadores no bloqueantes utilizando funcion Millis()
struct timerVar {
  unsigned long start_time;     // Tiempo de inicio para funcion Millis
  unsigned long time_period;    // Intervalo de tiempo para funcion Millis
};

//--------Conexion a internet (wifi)----------
const char* SSID_1 = "";                                                          // SSID de red WiFi #1
const char* SSID_2 = "";                                                          // SSID de red WiFi #2
const char* password_1 = "";                                                      // Contrasena de red WiFi
const char* SSID_3 = "";                                                          // SSID de red WiFi #3
const char* password_2 = "";                                                      // Contrasena de red WiFi

// Detalles del servidor para http
const char* host = "dweet.io";                                                    // Servidor de Dweet.io
const int port = 80;                                                              // Puerto de conexión para servidor HTTP
char jsonBuffer[JSON_BUFFER_SIZE];                                                // Buffer para envio de datos a servidor
int network_error_flag = 0;                                                       // Bandera indicadora de un error en la conexion WiFi
// https://dweet.io/get/dweets/for/hydro_test                                     // URL de servidor para lecturas de sensores
// https://dweet.io/get/dweets/for/hydro_LOG                                      // URL de servidor para informaci[on sobre el estado del sistema

WiFiClient espClient;  // Creacion de cliente para conexion WiFi del ESP32

//----------Variables de sensores-----------
float temp_s1 = 0.0;        // Variable para almacenar valor de temperatura en sensor DHT11 numero 1
float hum_s1 = 0.0;         // Variable para almacenar valor de humedad en sensor DHT11 numero 1
float temp_s2 = 0.0;        // Variable para almacenar valor de temperatura en sensor DHT11 numero 2
float hum_s2 = 0.0;         // Variable para almacenar valor de humedad en sensor DHT11 numero 2
float w_temp_s1 = 0.0;      //      ||          ||      ||   || temperatura en sonda DS18B20 numero 1
float w_temp_s2 = 0.0;      //      ||          ||      ||   ||      ||     en sonda DS18B20 numero 2
float w_temp_s3 = 0.0;      //      ||          ||      ||   ||      ||     en sonda DS18B20 numero 3
float ambient_T_min = 0.0;  //      ||          ||      ||   ||      ||     ambiental minima admisible
float ambient_T_max = 0.0;  //      ||          ||      ||   ||      ||     ambiental maxima admisible
float ambient_H_min = 0.0;  //      ||          ||      ||   || humedad ambiental minima admisible
float ambient_H_max = 0.0;  //      ||          ||      ||   ||    ||   ambiental maxima admisible
float setup_temp = 0.0;     //      ||          ||      ||   || temperatura promedio en el sistema
float setup_hum = 0.0;      //      ||          ||      ||   || humedad promedio en el sistema
float phMaxVal = 0.0;       //      ||          ||      ||   || pH maximo admisible
float phMinVal = 0.0;       //      ||          ||      ||   || pH minimo admisible
float ph_val = 0.0;         //      ||          ||      ||   || de pH del sensor de Atlas Scientific

int ambient_temperature_flag = 0;          // 0 = valor normal, 1 = valor bajo, 2 = valor alto
int ambient_humidity_flag = 0;             // 0 = valor normal, 1 = valor bajo, 2 = valor alto
int dht_retry_cont = 0;                    // Cantidad de intentos utilizados para obtener datos de sensores DHT
int dht_max_retry = 2;                     // Cantidad maxima de intentos permitidos para obtener datos de sensores DHT
int fan_activate = 0;                      // Bandera para activar ventiladores
int fan_state = IDLE;                      // Bandera para registrar estado actual de los ventiladores
int control_active_flag = 0;               // Indicador de estado de control (0 = control inactivo <parametros normales> | 1 = control activo)
unsigned long previous_millis_dht = 0;     // 
unsigned long glt_prev_time = 0;           // Estado anterior del temporizador de luz de crecimiento (Grow Light Timer)
unsigned long global_timer_prev_time = 0;  // Estado anterior de temporizador global
unsigned long previous_dispense_time = 0;  // Estado anterior de temporizador de liberador de soluciones reguladoras de pH

//-------------Contadores------------
double active_time = 0;                    // Tiempo que han estado activas las luces de crecimiento
int http_send_fail_counter = 0;            // Contador de fallos de envio de datos utilizando HTTP
int sre_cont = 0;                          // Contador para eventos de lectura de sensores (Sensor Reading Event Counter)
int dse_cont = 0;                          // Contador para eventos de envío de datos (Data Send Event Counter)
int cse_cont = 0;                          // Contador para eventos del sistema de control (Control System Event Counter)
int wre_cont = 0;                          // Contador para evento de reconexión a red WiFi (WiFi Recconect Event Counter)
int wifi_retry_cont = 0;                   // Contador de cantidad de veces que se ha reintentado la conexion a red WiFi

//-----------------------Variables generales---------------
const int ledPin = 2;                      // Pin para luz led interna del ESP32
int ledState = LOW;                        // Estado para la luz led del ESP32
int neo_pixel_state = 0;                   // Estado para la luz de crecimiento (Neopixel)
double growLightTime = 14;                 // Valor en horas (revisar pagina 14, tesis hidroponia)
int time_of_day = 0;                       // Hora del dia (1 = dia, 0 = noche)
uint8_t day_timer = 0;                     // Registro de horas para determinar la hora actual y activar luces de crecimiento a la hora establecida
uint8_t morning_time = 6;                  // am - Hora local a la que amanece
uint8_t night_time = 17;                   // pm - Hora local a la que anochece

//--------------Inicializacion de modulos del sistema----------------
DHT dht_s1(DHTPIN, DHTTYPE);                                                      // Activar sensor DHT11 numero 1
DHT dht_s2(DHTPIN2, DHTTYPE);                                                     // Activar sensor DHT11 numero 1
OneWire oneWire(ONE_WIRE_BUS);                                                    // Bus de comunicacion para sensores de protocolo onewire
DallasTemperature sensors(&oneWire);                                              // Inicializacion de sensores de temperatura de agua
DeviceAddress tankSensor, growChannel1, growChannel2;                             // Definicion de sensores de temperatura de agua
Adafruit_NeoPixel NeoPixel(NUM_PIXELS, NEOPIXELPIN, NEO_GRB + NEO_KHZ800);        // Definicion de luces led (NEOPIXELS)
Adafruit_NeoPixel NeoPixel2(NUM_PIXELS + 1, NEOPIXELPIN2, NEO_GRB + NEO_KHZ800);  // Definicion de luces led (NEOPIXELS) de la repisa superior
RTC_DS3231 rtc;                                                                   // RTC conectado a pines SCL y SDA: 22 y 21
Servo phUpServo, phDownServo;                                                     // Servomotores para control de valvulas de regulacion de pH
WiFiMulti wifiMulti;                                                              // Inicializacion de objeto para manejar multiples redes WiFi

//---------------------------------Prototipos de funciones---------------------------------
void multiWifi();                                                                                                    // Establecer conexion WiFi
bool httpPostRequest(int sel);                                                                                       // Envio de datos a servidor WiFi
void getTemperatureHumidity();                                                                                       // Lectura de sensores de temperatura y humedad
String packageData(float val1, float val2, float val3, float val4, float val5, float val6, float val7, float val8);  // Empaquetado de dat648213os en formato JSON
String performanceLog();                                                                                             // Empaquetado de datos para log de rendimiento
String getCurrentTime(int sel);                                                                                      // Lectura de tiempo real (mediante modulo RTC DS3231)
float twoValAverage(float dat1, float dat2);                                                                         // Calculo de valor promedio para dos valores
void fanControl();                                                                                                   // Accionamiento de ventiladores
void ambientAirParamsControl();                                                                                      // Control de parametros ambientales
void waterTempInit();                                                                                                // Iniciar sensores de temperatura de agua
float getWaterTemperature(DeviceAddress deviceAddress);                                                              // Lectura de sensores de temperatura de agua
void setNeopixelState();                                                                                             // Cambiar el estado de los leds segun tiempo recorrido
void dayCounter();                                                                                                   // Determinar hora del dia y actualizarla segun requerido
void phRegulationControl();                                                                                          // Regulacion de pH

/*
=====================================================================================================================================================================================
============================================================================INICIA PROGRAMA==========================================================================================
=====================================================================================================================================================================================
*/
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
void loop() {
  //-----------------Lectura de la hora del dia--------------------
  dayCounter();

  //-----------------Actualizacion de luces de crecimiento---------------
  setNeopixelState();

  //-------------------------Inicializacion de variables---------------------------------
  int sre_period = (control_active_flag == 0) ? 5 : 2;   // Leer sensores cada 2.5 minutos o cada minuto (si el control esta activo)
  int dse_period = (control_active_flag == 0) ? 10 : 6;  // Envio de datos cada 5 minutos o cada 3 minutos (si el control esta activo)
  int cse_period = (control_active_flag == 0) ? 10 : 4;  // Actualizar ciclo de control cada 5 minutos o cada 2 minutos (si el control esta activo)
  int wre_period = 16;                                   // Intentar reconexion a red WiFi cada 8 minutos

  struct timerVar global_timer;                         // Temporizador global para eventos | utilizando periodo de 30 segundos
  global_timer.start_time = millis();
  if (global_timer.start_time - global_timer_prev_time >= GLOBAL_PERIOD)  // Ingresar a ciclo cada 30 segundos
  {
    global_timer_prev_time = global_timer.start_time;   // Actualizar tiempo del temporizador

    //--------------------------Incrementar contadores de eventos----------------------------------
    sre_cont++;  // Contador de Evento de Lectura de Sensores (Sensor Reading Event Counter)
    dse_cont++;  // Contador de Evento de Envio de Datos (Data Send Event Counter)
    cse_cont++;  // Contador de Evento de Sistemas de Control (Control System Event Counter)
    wre_cont++;  // Contador de Evento de Reconexion de WiFi (Wifi Reconnect Event COunter)

    //---------------------------Evento de Lectura de Datos------------------------------------
    if (sre_cont >= sre_period) {
      sre_cont = 0;                                   // Reiniciar contador
      dht_retry_cont = 0;                             // Reiniciar contador de intentos de lectura de sensor DHT
      getTemperatureHumidity();                       // Lectura de sensores DHT11

      sensors.requestTemperatures();                  // Solicitud de valores de temperatura
      w_temp_s1 = getWaterTemperature(tankSensor);    // Lectura de sensores DS18B20  (Sonda en deposito de agua)
      w_temp_s2 = getWaterTemperature(growChannel1);  //      |||       |||||         (Sonda en canal de crecimiento 1)
      w_temp_s3 = getWaterTemperature(growChannel2);  //      |||       |||||         (Sonda en canal de crecimiento 2)
      ph_val = pH.read_ph();                          // Lectura de sensor de pH
    }

    //--------------------------------Evento de Sistemas de Control--------------------------------
    if (cse_cont >= cse_period) {
      cse_cont = 0;                                   // Reiniciar contador

      // Analizar parametros y ejecutar ciclos de control
      ambientAirParamsControl();                      // Control de parametros del aire
      phRegulationControl();                          // Control de pH
      fanControl();                                   // Actuacion de ventiladores
    }

    //---------------------------------Evento de Envio de Datos------------------------------------
    if (dse_cont >= dse_period) {
      dse_cont = 0;                                   // Reiniciar contador
      if (httpPostRequest(0)) {                       // Si el envio de datos a servidor 1 es exitoso
        http_send_fail_counter = 0;                   // Mantener en 0 la bandera de fallo de envio de datos por HTTP
      } else {                                        // De lo contrario:
        network_error_flag = 1;                       // Activar bandera de fallo de envio de datos a servidor
      }
      if (httpPostRequest(1)) {                       // Si el envio de datos a servidor 2 es exitoso
        http_send_fail_counter = 0;                   // Mantener en 0 la bandera de fallo de envio de datos por HTTP
      } else {                                        // De lo contrario:
        network_error_flag = 1;                       // Activar bandera de fallo de envio de datos a servidor
      }
    }

    //---------------------------------Evento de Reconexion WiFi--------------------------------
    if (wre_cont >= wre_period) 
    {
      wre_cont = 0;                                   // Reiniciar contador
      if (network_error_flag == 1 || WiFi.status() != WL_CONNECTED) // Intentar reconexion WiFi si el sistema esta desconectado o existio un error
      {
        wifi_retry_cont++;                            // Incrementar contador de intentos de reconexion
        multiWifi();                                  // Funcion para conexion a red WiFi
      } 
      else
      {
        network_error_flag = 0;                       // Mantener bandera en cero si existe conexion WiFi
      }
    }
  }

  //-----------------------------------Revisar Conexion WiFi-------------------------------
  if (WiFi.status() == WL_CONNECTED && digitalRead(ledPin) != HIGH) // Si se esta conectado a red WiFi y el led indicador esta apagado
  {
    ledState = HIGH;                                  // Cambiar estado del led indicador a Alto (encendido)
    digitalWrite(ledPin, ledState);                   // Actualizar led indicador
    network_error_flag = 0;                           // Limpiar bandera de error de conexion
  } 
  else if (WiFi.status() != WL_CONNECTED && digitalRead(ledPin) != LOW) // Si no esta conectado a red WiFi y el led indicador esta encendido
  {
    ledState = LOW;                                   // Cambiar estado del led indicador a Bajo (apagado)
    digitalWrite(ledPin, ledState);                   // Actualizar led indicador
    network_error_flag = 1;                           // Activar bandera de error de conexion
  }
}

/*
=====================================================================================================================================================================================
========================================================================FUNCIONES DEL SISTEMA========================================================================================
=====================================================================================================================================================================================
*/

void multiWifi()  // Gestion de multiples redes WiFi y conexion a red con mejor senal
/*
Utiliza el metodo .run() para conectar a la red WiFi en la lista definida en la funcion setup().
La funcion analiza la intensidad de la sennal de cada red WiFi disponible (RSSI) 
y conecta automaticamente a la de mayor intensidad.
*/
{
  // Reiniciar ESP32 si es de noche y se perdio la conexion a red WiFi
  if(time_of_day == 0 && network_error_flag == 1)
  {
    ESP.restart();                                    // Reiniciar ESP32
  }
  
  if (wifiMulti.run() == WL_CONNECTED)                // Si se establecio correctamente la conexion WiFi
  {
    network_error_flag = 0;                           // Limpiar bandera de error de conexion
    wifi_retry_cont = 0;                              // Reiniciar contador de intentos de conexion WiFi
    digitalWrite(ledPin, HIGH);                       // Encender led indicador
  } else {                                            // De lo contrario
    network_error_flag = 1;                           // Activar bandera de error de conexion
  }
}
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

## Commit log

2024-11-08 Creacion de archivo "Codigo Fuente"
2024-11-08 Creacion de archivo "Datos"
2024-11-08 Creacion de archivo "Documentos"
2024-11-08 Creacion de archivo "Modelos CAD"
2024-11-08 Creacion de archivo "Desarrollo PCB"
2024-11-08 Creacion de archivo "OldVersions"
2024-11-08 Revert "Creacion de archivo "OldVersions""
    This reverts commit 23246414dd41c2f8cace71364e108e038bcb6904.
2024-11-08 Creacion de folder "Codigo Fuente" con archivo "Indice"
2024-11-08 Crear folder "Modelos CAD" con archivo "Indice"
2024-11-08 Crear folder "Desarrollo PCB" con archivo "Indice"
2024-11-09 Agregar src de applicacion de Android
    [ic_app_logo.xml, ic_app_logo_background.xml, ic_app_logo_round.xml]
2024-11-09 Script para realizar historico de datos
2024-11-09 Datos recopilados en formato .csv
    Datos recopilados de variables obtenidas del sistema en diferentes fechas de prueba.
    [temperature_history_12-13_10_24.csv, temperature_history_13-14_10_24.csv, temperature_history_20-21_10_24.csv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]
2024-11-09 Documentos de diseño de PCB
    [PCB_Tesis_v2_2024.dxf]
2024-11-09 Agregar versiones pasadas de firmware del sistema
2024-11-09 Protocolo de tesis
2024-11-09 Agregar proyecto empaquetado
    Proyecto empaquetado para visualización de la estructura del sistema.
2024-11-09 Componentes CAD adicionales
    [TH_acople_servo_valvula.ipt, TH_fan_holder.ipt]
2024-11-09 Agregar documentacion de trabajo escrito (tesis)
2024-11-09 Diseño de PCB
2024-11-09 Añadir version de Altium Designer de diseño PCB
    [PCB_Tesis_v2_2024-11-08.pcbdoc, Sheet_1_2024-11-08.schdoc]
2024-11-09 Agregar imagenes de PCB
2024-11-09 Activar funcion de control de servomotores
2024-11-16 Agregar nombre de linea de investigacion
